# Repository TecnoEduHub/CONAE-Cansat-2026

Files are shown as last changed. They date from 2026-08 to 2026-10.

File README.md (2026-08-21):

# CANSAT 2026 — E.E.S.T. N.º5 "Amancio Williams"

Repositorio destinado a documentar el proceso de participación de la **Escuela de Educación Secundaria Técnica N.º 5 "Amancio Williams" de Mar del Plata** en el **Certamen CANSAT Secundario 2026**, organizado por la **Comisión Nacional de Actividades Espaciales (CONAE)**.

Este repositorio tiene como objetivo conservar el registro del proceso realizado por los estudiantes y docentes de la Técnica N.º 5.

La documentación irá incorporando progresivamente:

- Diseño conceptual.
- Documento Preliminar de Diseño.
- Investigación y antecedentes.
- Diseño electrónico.
- Programación y firmware.
- Diseño mecánico.
- Sistema de descenso.
- Misión primaria.
- Misión secundaria.
- Pruebas y validaciones.
- Fotografías y videos.
- Informes de avance.
- Problemas encontrados y soluciones adoptadas.
- Presentaciones y material de difusión.

La intención es que el repositorio no sea solamente un lugar donde almacenar el resultado final, sino una **bitácora técnica y educativa del proceso de aprendizaje**.

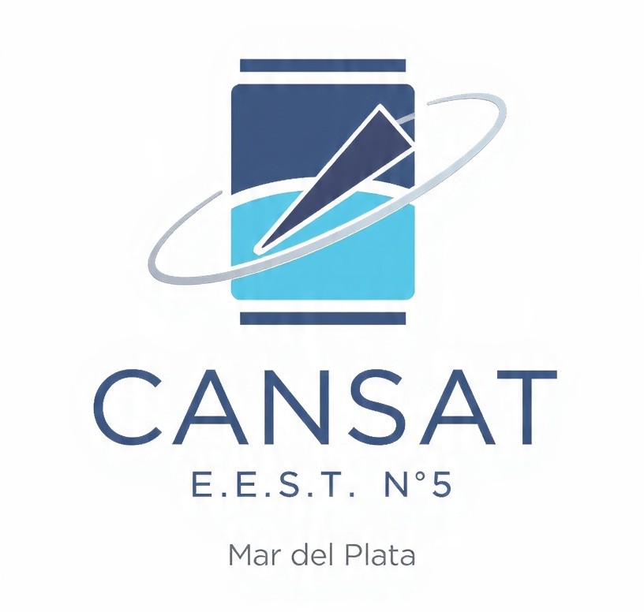
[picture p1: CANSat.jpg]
CANSAT 2026 - Técnica N.º 5


Durante la convocatoria, nuestra institución estuvo representada por dos equipos:

| Equipo | Resultado |
|---|---|
| **A.N.T.I.R.** | Actualmente en la **Etapa 4 — Construcción, seguimiento y validación** |
| **PENTA Space** | Llegó a la **Etapa 3 — Selección de proyectos y recepción del kit** |

Ambos equipos realizaron un excelente trabajo a lo largo de la competencia, atravesando un proceso de aprendizaje que involucró ciencia, electrónica, programación, diseño, experimentación, documentación y trabajo en equipo.

## ¿Qué es CANSAT?

**CANSAT** es una iniciativa educativa vinculada al ámbito espacial que propone a estudiantes de escuela secundaria asumir el desafío de diseñar, construir, probar y operar un **satélite a escala**.

El nombre surge de la combinación de las palabras **CAN** (lata) y **SAT** (satélite), debido a que la carga útil debe estar contenida dentro de un volumen aproximadamente equivalente al de una lata de gaseosa.

En Argentina, la convocatoria es organizada por la **Comisión Nacional de Actividades Espaciales (CONAE)** y busca acercar la ciencia y la tecnología a estudiantes de todo el país. El desafío reproduce, a pequeña escala, distintas etapas de una misión espacial: desde la concepción y el diseño hasta la construcción, validación, lanzamiento y operación del sistema.

Además del desarrollo tecnológico, la propuesta busca fortalecer competencias relacionadas con las disciplinas **STEM —Ciencia, Tecnología, Ingeniería y Matemáticas—**, promover el pensamiento científico y favorecer el trabajo colaborativo.

## El desafío

Cada equipo debe desarrollar una **carga útil** de dimensiones reducidas, contenida dentro de un cilindro de aproximadamente el tamaño de una lata.

El CANSAT es transportado mediante un cohete hasta una determinada altura y posteriormente desciende mediante un sistema de descenso controlado, generalmente un paracaídas. Durante el descenso debe realizar mediciones y transmitir los datos correspondientes a la misión.

La **misión primaria** establecida para CANSAT 2026 consiste en realizar, durante el descenso, un **sondeo atmosférico de presión y temperatura**.

La convocatoria también contempla una **misión secundaria**, mediante la cual cada equipo puede incorporar una actividad adicional. Para esta edición se propuso como objetivo la obtención de una imagen o video durante el lanzamiento, apogeo y/o trayectoria de descenso.

El desafío no consiste únicamente en construir un dispositivo electrónico. Los estudiantes deben trabajar como un verdadero equipo de misión: investigar, diseñar, programar, construir, documentar, realizar pruebas, analizar resultados y comunicar sus decisiones técnicas.

## Etapas de la convocatoria

La competencia se estructura en **cinco etapas eliminatorias**. Cada instancia debe ser aprobada para poder avanzar a la siguiente.

### Etapa 1 — Capacitación

Los estudiantes y docentes participan de una capacitación virtual destinada a incorporar los conocimientos, herramientas y materiales necesarios para desarrollar el proyecto.

La capacitación combina contenidos asincrónicos con instancias sincrónicas y finaliza con una evaluación.

### Etapa 2 — Diseño y presentación del proyecto

Cada equipo debe elaborar y presentar su propuesta.

Entre los principales entregables se encuentran:

- **Documento Preliminar de Diseño (DPD)**.
- **Video de presentación del equipo**.
- Descripción de la misión primaria y secundaria.
- Organización y roles de los integrantes.

La evaluación considera tanto el proyecto técnico como la capacidad del equipo para comunicar sus ideas.

### Etapa 3 — Selección y kit de materiales

Los proyectos son evaluados por un jurado y se seleccionan aquellos que resultan factibles, originales y que evidencian el compromiso y la capacidad de los equipos.

Los proyectos seleccionados reciben un **kit de materiales** para continuar con la construcción del CANSAT.

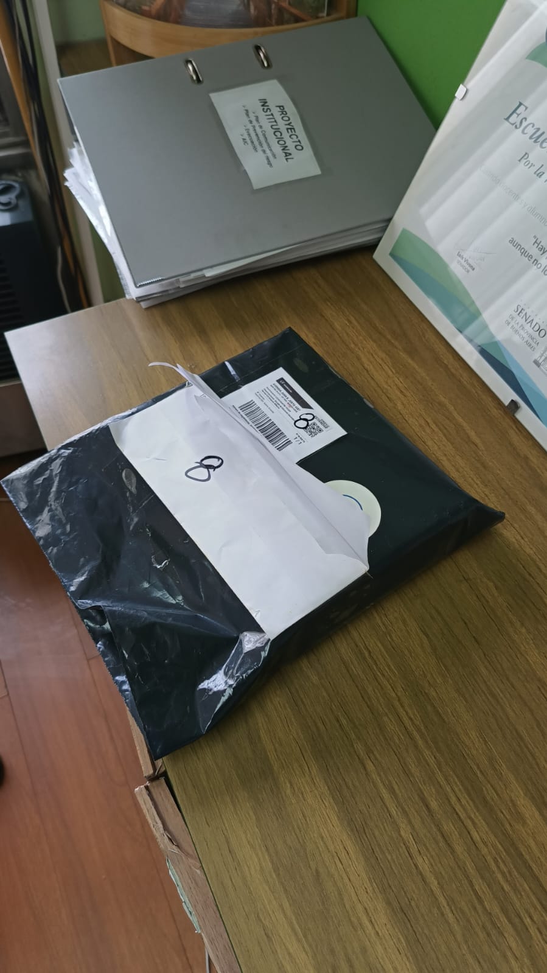
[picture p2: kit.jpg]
Llegada del kit CANSAT a la Técnica N.º 5


**Llegada del kit de materiales de CONAE a nuestra escuela.**

### Etapa 4 — Construcción, seguimiento y validación

Los equipos seleccionados construyen el prototipo diseñado y deben presentar diferentes evidencias de avance, incluyendo documentación, fotografías, videos y otros materiales solicitados.

Al finalizar esta instancia se realiza una validación mediante una videollamada con especialistas, en la que se presenta el prototipo y se revisa su funcionamiento.

De esta instancia se seleccionan los **cinco equipos** que participan de la campaña de lanzamiento, además de las correspondientes menciones especiales.

### Etapa 5 — Campaña de lanzamiento

Los cinco equipos seleccionados participan de la campaña de lanzamiento de sus CANSAT y realizan las mediciones correspondientes.

La convocatoria establece que los equipos seleccionados reciben cobertura de transporte, alojamiento y pensión completa para estudiantes y docentes responsables. 

## Nuestra participación

La Técnica N.º 5 tuvo la posibilidad de presentar **dos equipos** en CANSAT 2026, alcanzando ambos un desempeño destacado.

La convocatoria permite la participación de hasta dos equipos por institución. Cada equipo debe estar integrado por entre tres y cinco estudiantes y contar con el acompañamiento de un docente responsable.

### Equipo A.N.T.I.R.

**A.N.T.I.R.** es uno de los equipos representantes de la Escuela de Educación Secundaria Técnica N.º 5 "Amancio Williams".

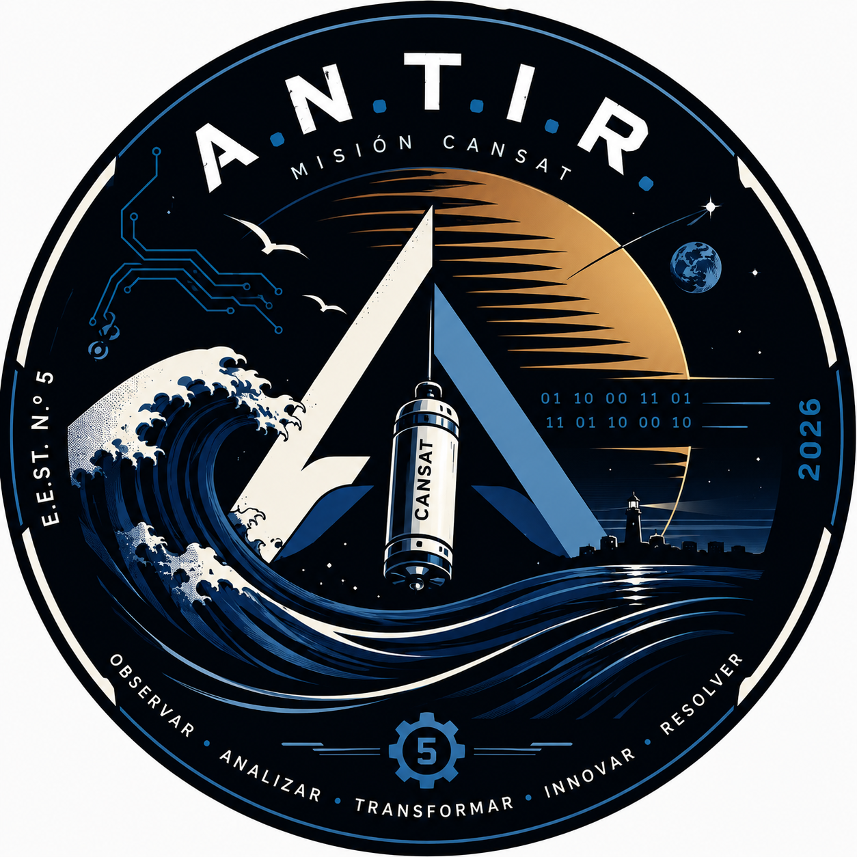
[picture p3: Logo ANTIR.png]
Logo del equipo ANTIR


El equipo actualmente logró avanzar hasta la:

> **Etapa 4 — Construcción, seguimiento y validación de los CANSAT**

Esto implicó superar las etapas iniciales de capacitación, presentación del proyecto y selección de propuestas, para luego recibir el kit de materiales y avanzar en la construcción y validación del prototipo.

En esta etapa el trabajo pasó del diseño conceptual a la implementación concreta: integración de hardware, programación, construcción mecánica, pruebas, documentación y preparación de las evidencias solicitadas por CONAE.

## Equipo PENTA Space

**PENTA Space** fue el segundo equipo que representó a la Técnica N.º 5 "Amancio Williams" en CANSAT 2026.

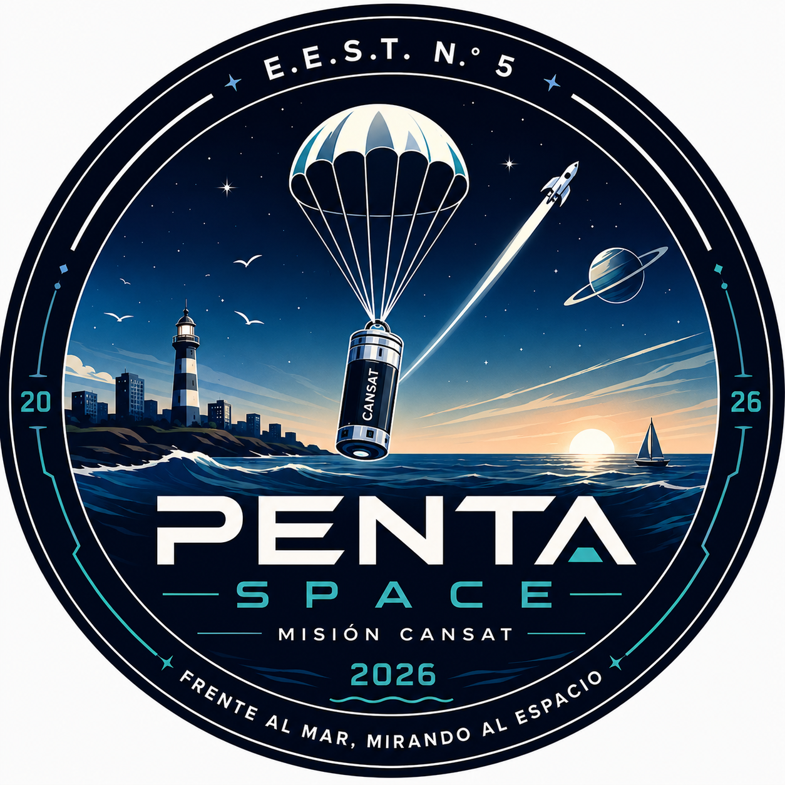
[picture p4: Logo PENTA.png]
Logo del equipo PENTA Space


El equipo logró avanzar hasta la:

> **Etapa 3 — Selección de proyectos y envío del kit de materiales**

Esto significa que su propuesta superó las instancias iniciales de capacitación y evaluación del proyecto, alcanzando la selección que habilitaba a los equipos a continuar con el desarrollo del prototipo.

Aunque el recorrido de PENTA Space finalizó en esta etapa, su participación constituyó un importante proceso de aprendizaje y desarrollo de competencias técnicas y de trabajo en equipo.

## Resultados de la convocatoria

La edición 2026 contó con **257 equipos inscriptos**, de los cuales **120 presentaron su propuesta** mediante el Documento Preliminar de Diseño.

La evaluación estuvo a cargo de un jurado integrado por profesionales de la **Universidad Tecnológica Nacional (UTN)**, la **CONAE** y la **Asociación de Cohetería Experimental y Modelista de Argentina (ACEMA)**.

Los equipos ubicados entre los puestos 1 y 20 fueron invitados a pasar a la siguiente etapa, mientras que los puestos 21 al 40 recibieron una mención de honor por su destacada participación.

La propia organización destacó la elevada calidad de los trabajos presentados y lo ajustado de los puntajes obtenidos. 

## Criterios de evaluación

A lo largo de la convocatoria, los proyectos son evaluados considerando diferentes aspectos:

- **Admisibilidad:** cumplimiento de los requisitos formales.
- **Presentación:** calidad y cumplimiento de las entregas, organización del equipo y comunicación del proyecto.
- **Creatividad:** originalidad del diseño y de la misión secundaria.
- **Viabilidad:** factibilidad de realización y planificación de las pruebas.
- **Relevancia:** claridad, pertinencia, grado de avance y complejidad de la propuesta.

Estos criterios hacen que CANSAT sea mucho más que una competencia de construcción de un dispositivo: el proceso completo de planificación, documentación, validación y comunicación forma parte del desafío. 

## Recursos

- [Capacitación y videos del proyecto](https://drive.google.com/drive/folders/1EPjXjjoXwsOttx_nsDYTwsNPLpWK6ylc?usp=sharing)

- [Comisión Nacional de Actividades Espaciales](https://www.argentina.gob.ar/ciencia/conae)

- [Asociación de Cohetería Experimental y Modelista Argentina](https://www.acema.com.ar/)

## Agradecimientos

A la **Comisión Nacional de Actividades Espaciales (CONAE)** por impulsar esta propuesta educativa y brindar a estudiantes de escuelas secundarias de todo el país la posibilidad de acercarse al desarrollo de tecnología espacial.

A **ACEMA** y a todos los profesionales que participaron de la capacitación, evaluación y acompañamiento de los equipos.

Y, especialmente, a los estudiantes de **A.N.T.I.R.** y **PENTA Space**, por el compromiso, la creatividad, el trabajo técnico y la dedicación demostrados durante todo el proceso.

Independientemente de la etapa alcanzada por cada equipo, ambos representaron a la **Escuela de Educación Secundaria Técnica N.º 5** y dejaron un valioso registro de aprendizaje, experimentación y trabajo colaborativo.

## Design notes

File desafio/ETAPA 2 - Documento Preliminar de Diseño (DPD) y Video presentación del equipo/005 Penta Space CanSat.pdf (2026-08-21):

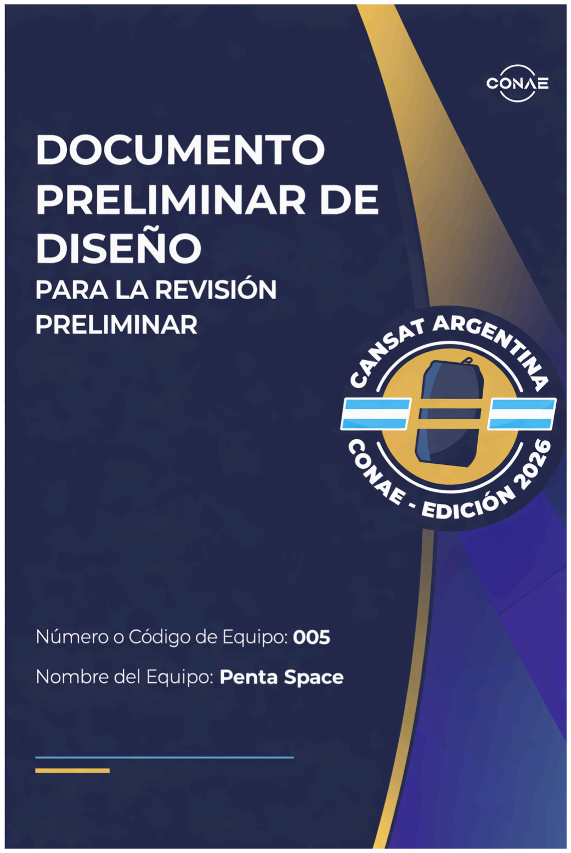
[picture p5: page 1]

# DATOS

CÓDIGO CONAE (NRO):
005

NOMBRE DEL EQUIPO:
Penta Space

Colegio/Institución:
E.E.S.T. N.°5 Amancio Williams (Mar Del Plata)

Miembros del equipo:
-Geronimo Octavio Luciano Villagran -Acosta Pedro
-Petagna Ordoñez Bautista Jeremias -Tiago Lionel Ramirez
-Mauro Nehemias Castro

Tutor responsable:
- Lucas Martin Treser

# NOMBRE DE LA MISIÓN

Parche:

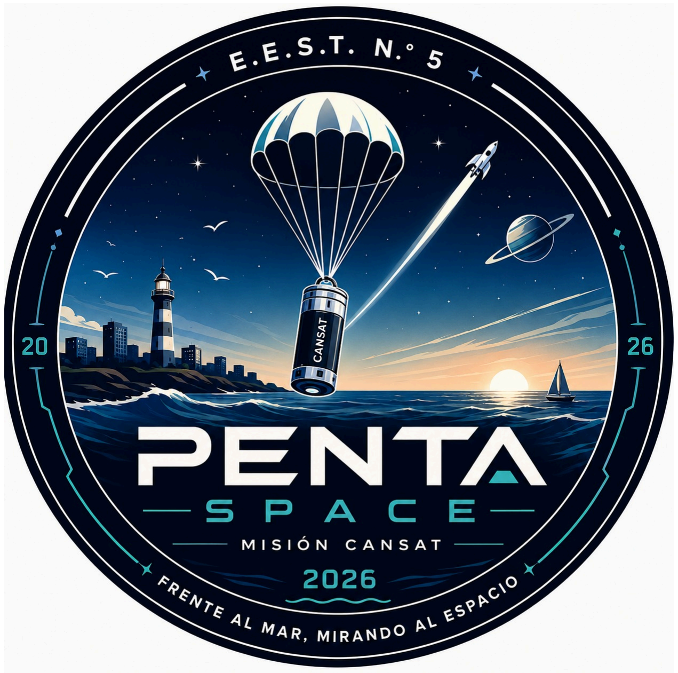
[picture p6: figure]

Organización del equipo: Roles
Geronimo Octavio Luciano Villagran: Desarrollo de Hardware Acosta Pedro: Estructura y Diseño
Petagna Bautista: Programación y comunicación
Tiago Lionel Ramirez: Montaje y Soldadura
Mauro Nehemias Castro: Organización y telecomunicación

# Objetivos de la misión

La misión primaria es:
Realizar un sondeo durante el descenso del CanSat y nos piden medir únicamente presión y temperatura, a su vez resistir el lanzamiento, la caída y el impacto.
Debemos de diseñar una carcasa capaz de soportar los componentes que tenga dentro de ella (microcontroladores, carga útil, etc)
Queda totalmente prohibido que la carcasa sea de materiales tóxicos al ser humano o que contaminen el medio ambiente o tener material peligroso en el CanSat (por ejemplo químicos o explosivos)

La misión secundaria que proponemos es:
-Grabar video/ sacar fotos
-Medir la radiación uv
-Medición de la humedad
-Altura
-Ubicación geográfica

Todas estas mediciones se registrarán en base a la altura para tener un criterio al cual tener una referencia de registro para calcular a qué altura aumentan o disminuyen estas mediciones.

Justificación: La misión secundaria del CanSat busca ayudarnos a entender mejor cómo se comportan los fenómenos atmosféricos y a poner en práctica la integración de distintos sistemas en una plataforma muy pequeña. Vamos a medir humedad, radiación UV, temperatura y altura para analizar cómo cambian las condiciones de la atmósfera a medida que el satélite desciende. Estos datos pueden servir para estudios meteorológicos, ambientales y también para aprender más en el ámbito educativo. Además, el uso de una cámara y la transmisión de imágenes por el enlace NRF nos permitirá relacionar las observaciones visuales con los datos físicos obtenidos.

# DISEÑO PRELIMINAR

LAYOUT FÍSICO: Esta es la base del diseño exterior del CanSat. La estructura podrá estar sujeta a modificaciones y mejoras durante el desarrollo del proyecto, pero se mantendrá el orden general de los módulos y componentes dispuesto en la imagen.

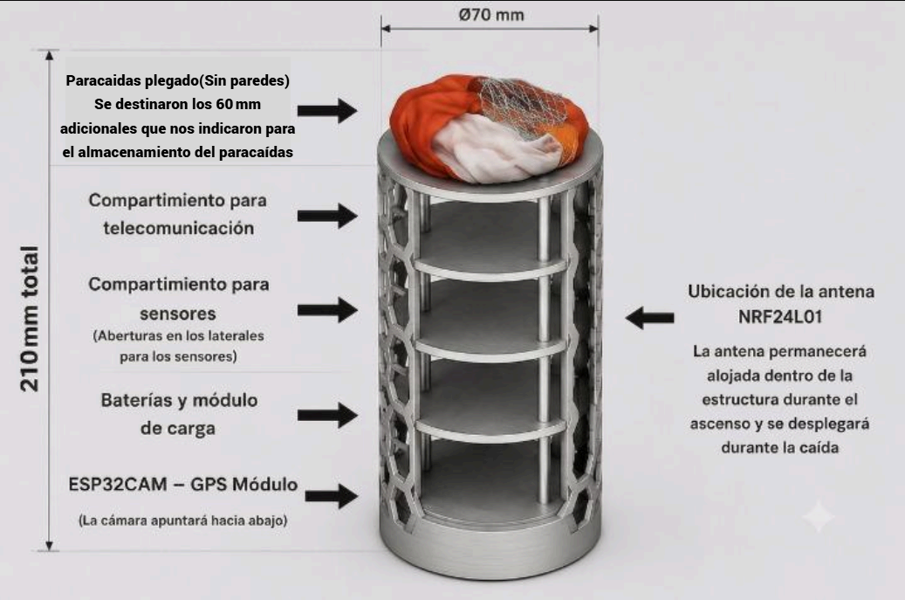
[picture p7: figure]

OPERACIONES:
Comportamiento de carga útil:
La carga útil deberá mantener un funcionamiento estable y confiable durante las fases del vuelo. Se espera que los sensores y sistemas electrónicos operen correctamente desde el lanzamiento hasta el aterrizaje y recuperación, garantizando la adquisición y transmisión de datos. Durante el descenso del CanSat, los sensores iniciarán las mediciones y recopilarán los datos atmosféricos y de movimiento, mientras el sistema de telecomunicaciones enviará la información hacia la estación terrena. Se espera detectar y registrar las variaciones de temperatura, presión atmosférica y altitud, junto con otros parámetros relevantes, reflejando los cambios que ocurren conforme el satélite desciende.

# SUBSISTEMAS

Un subsistema es un conjunto de componentes que forma parte de un sistema mayor y cumple una función específica dentro de él. Aunque cada subsistema puede realizar tareas particulares, todos trabajan de manera coordinada e interconectada para que el sistema completo cumpla su misión.

Electrónica: Es el subsistema encargado de adquirir, procesar y gestionar la información proveniente de los distintos sensores y dispositivos del CanSat.

Los componentes que se utilizarán son:

-ESP32-CAM S3: Microcontrolador principal con cámara integrada. Se encarga de capturar imágenes, procesar los datos de los sensores y controlar el funcionamiento general del sistema.
-Módulo + PA/LNA: Módulo de comunicación por radiofrecuencia de corto y medio alcance (2,4 GHz).
-Módulo LoRa: Módulo de comunicación por radiofrecuencia de largo alcance.
-Sensor BME280: Mide presión atmosférica, temperatura y humedad. -Sensor UV ML8511: Mide el nivel de radiación ultravioleta.
-GPS NEO-7M: Proporciona la posición geográfica (latitud y longitud) y la altitud del CanSat.
Electrónica de potencia: Es el subsistema encargado de suministrar, distribuir y regular la energía eléctrica necesaria para el funcionamiento de todos los componentes. Se utilizarán baterías 18350, elegidas por su tamaño compacto y su capacidad energética.
Telemetría: Es el subsistema encargado de transmitir la información obtenida por los sensores hacia la estación terrenal.
Para ello se utilizará un módulo de radiofrecuencia NRF24L01 + PA/LNA, que enviará los datos capturados por los sensores y las imágenes obtenidas por la cámara(Además de guardarlas en la tarjeta SD del módulo), permitiendo el monitoreo del CanSat en tiempo real.
Cámara: Es el subsistema encargado de capturar imágenes durante toda la misión. La cámara estará integrada en la ESP32-CAM, recibirá alimentación del subsistema de potencia y las imágenes podrán ser transmitidas mediante el sistema de telemetría o a través de la tarjeta sd del módulo.
Sistema de descenso: Es el subsistema responsable de garantizar un descenso seguro y controlar la velocidad de caída del CanSat.
Se utilizará un paracaídas, cuya función será reducir la velocidad de descenso para proteger la electrónica, la estructura y la carga útil durante el aterrizaje, además de asegurar una velocidad adecuada para realizar mediciones precisas durante la fase de descenso.

# PRESUPUESTO DE MASA

Componente | Cantidad | Masa Unitaria (g) | Masa Total (g)
ESP32-CAM | 1 | 18 | 18
Módulo NRF24L01+ PA/LNA (a bordo) | 1 | 24 | 24
Módulo LoRa (a bordo) | 1 | 8 | 8
Sensor BME280 | 1 | 3 | 3
Sensor UV ML8511 | 1 | 2 | 2
GPS NEO-7M | 1 | 18 | 18
Batería Li-ion 18350 | 2 | 23 | 46
Módulo de carga TP4056 | 1 | 3 | 3
PCB personalizada FR4 optimizada | _ | 18 | 18
Carcasa impresa en PLA optimizada | 1 | 50 | 50
Paracaídas Ripstop Ø50 cm + 8 cuerdas | 1 | 22 | 22
Cableado y conectores | _ | _ | 10
Tornillería y separadores optimizados | _ | _ | 10
Masa total estimada | _ | _ | 232g

El presupuesto de masas se realizó considerando únicamente los componentes de la carga útil del CANSAT. Las masas se obtuvieron a partir de las especificaciones técnicas de los fabricantes y de estimaciones para los elementos de fabricación propia, como la PCB y la carcasa impresa en PLA. La masa total estimada es de 232g, cumpliendo con las restricciones del proyecto y dejando un margen para posibles ajustes durante la integración. Antes del lanzamiento, se verificará la masa total del sistema mediante una balanza digital de precisión.

# INTEGRACIÓN Y PRUEBAS

### Pruebas preliminares de los componentes:

Antes de realizar el ensamblaje definitivo del CanSat, se verificará de manera individual el correcto funcionamiento y calibración de cada periférico aprovechando las instalaciones escolares y entornos públicos cercanos:

Sensor BME280 (Presión, Temperatura y Humedad): Se realizarán mediciones iniciales en ambientes controlados dentro de las aulas y talleres del colegio para registrar la estabilidad térmica y de humedad. Para comprobar el correcto funcionamiento del barómetro respecto a las variaciones de altitud, se utilizarán las escaleras de la institución y el puente de la escuela (de interconexión de las aulas), contrastando los cambios de presión relativa con la altura geométrica real de los pisos.

Sensor UV ML8511 (Radiación Ultravioleta): Se medirá su respuesta en zonas interiores bajo luz artificial (donde el nivel de radiación UV debe aproximarse a cero). Posteriormente, el equipo se trasladará a espacios abiertos (como el patio del colegio o la plaza pública cercana) expuesto directamente a la radiación solar para validar el incremento en el voltaje de salida y su correcta fluctuación de acuerdo con la intensidad del sol.

GPS NEO-7M (Posición y Altitud): Las pruebas se llevarán a cabo al aire libre en la plaza o patio del colegio para asegurar una línea de visión directa y despejada con las constelaciones satelitales. Se registrará el tiempo de adquisición de señal (Time-To-First-Fix) y se validará que las coordenadas obtenidas correspondan con precisión a la localización geográfica en Mar del Plata.

ESP32-CAM S3 y Módulos de Comunicación (NRF24L01+ / LoRa): Se realizarán pruebas de transmisión de datos en tiempo real y captura de imágenes desde dependencias internas críticas como el Zoom y los talleres. Esto permitirá evaluar el alcance de los módulos de radiofrecuencia a través de obstáculos y muros, garantizando la estabilidad del enlace de telemetría.

### Secuencia de integración:

El proceso de ensamblaje físico y eléctrico del satélite se llevará a cabo de manera estructurada siguiendo los siguientes pasos consecutivos:

Inspección de la PCB: Revisión visual de la placa personalizada FR4 para comprobar la ausencia de cortocircuitos o fallas de continuidad en las pistas.

Montaje del Subsistema de Potencia: Soldadura del módulo de carga TP4056 y los portabaterías para las celdas Li-ion 18350. Se medirá con un multímetro digital que los voltajes de alimentación regulados (3.3V y 5V) sean estables.

Fijación del Microcontrolador y Módulos RF: Soldadura o inserción de la ESP32-CAM S3 y de las placas de comunicación NRF24L01+ y LoRa sobre la PCB.

Integración de Sensores Periféricos: Conexión de los sensores previamente validados (BME280, ML8511 y GPS) a los pines correspondientes de la placa madre.

Carga y Testeo del Firmware Base: Programación del firmware para verificar que la ESP32-CAM logre inicializar y leer todos los sensores simultáneamente sin congelamientos.

Encapsulado Mecánico: Introducción y fijación de la electrónica armada dentro de la carcasa impresa en PLA optimizada utilizando la tornillería y separadores correspondientes.

Anclaje del Sistema de Descenso: Sujeción de las líneas de cuerda del paracaídas Ripstop de a los puntos de sujeción de la estructura exterior. Pruebas de integridad:
Una vez integrado por completo el CanSat dentro de su contenedor, se someterá al conjunto a ensayos mecánicos y funcionales globales:

Prueba de Continuidad Operativa: Con el CanSat totalmente sellado, se encenderá mediante sus baterías y se dejará transmitiendo telemetría continua hacia la estación terrena por un lapso mínimo de 30 minutos. Se evaluará que no existan pérdidas de paquetes ni caídas de tensión eléctrica.

Prueba de Resistencia Mecánica y Vibración: Se realizarán pruebas manuales de agitación rigurosa en el taller para asegurar que el hardware interno permanezca firme y que ningún cable, conector o batería se desconecte ante las aceleraciones bruscas del lanzamiento.

Prueba de Despliegue del Paracaídas: Se simularán lanzamientos de caída libre controlada arrojando el CanSat de forma segura desde el puente de la institución o ventanas elevadas hacia una zona acolchada, verificando la apertura inmediata y correcta del paracaídas Ripstop, asegurando una velocidad de descenso controlada.

Plan de validación (medidas, peso, integridad, tests ambientales): Para garantizar que el prototipo cumple estrictamente con el reglamento de CONAE y que sus mediciones son fiables, se ejecutará el siguiente plan métrico:

Validación de Mediciones (Consistencia de Datos): Para certificar que lo que medimos está bien, las lecturas en tiempo real de telemetría ambiental se compararán lado a lado con instrumental de referencia comercial de taller (como un termómetro/higrómetro digital externo para contrastar el BME280) y dispositivos GPS móviles redundantes para comprobar la consistencia de coordenadas y altitudes del NEO-7M.

Validación de Peso (Presupuesto de Masa): El CanSat finalizado se colocará sobre una balanza digital de precisión del colegio para certificar que el peso total se ajusta a la masa estimada de 232 g, garantizando que permanezca holgadamente dentro de las restricciones reglamentarias de la misión.

Validación Dimensional (Medidas): Se utilizará un calibre métrico industrial para registrar el diámetro y altura final de la carcasa de PLA, verificando que respete el factor de forma cilíndrico estándar exigido (símil lata de bebida).

Tests Ambientales Térmicos: Para asegurar el comportamiento frente a bajas temperaturas en la atmósfera alta, se introducirá el sistema encendido dentro de una caja térmica refrigerada con hielo, supervisando que ni las baterías ni el procesamiento de la ESP32-CAM sufran degradación bajo condiciones climáticas frías.

# OPERACIÓN DE LA MISIÓN

Secuencia de eventos prevista:

Preparación: verificación del funcionamiento de los sensores, cámara, batería, sistema de almacenamiento y comunicaciones.
Integración: instalación del CanSat en el vehículo lanzador de acuerdo con los procedimientos establecidos por CONAE.
Lanzamiento: el CanSat es elevado hasta una altura aproximada de 200 a 400 metros.
Separación: el CanSat es liberado e inicia el descenso mediante un paracaídas. Desarrollo de la misión: durante el descenso se registran mediciones de temperatura, humedad, presión atmosférica, altitud, radiación UV y calidad del aire, mientras la cámara captura imágenes y/o video. Los datos se almacenan y, cuando es posible, se transmiten a la estación terrena.
Aterrizaje: el CanSat desciende de forma controlada y es recuperado por el equipo.
Recepción y análisis de datos: se descargan y procesan las mediciones e imágenes obtenidas para evaluar el desempeño del sistema y analizar las condiciones ambientales registradas durante la misión.
Roles y responsabilidades en la operación de la misión:

Director de misión: Coordina las actividades durante la campaña, supervisa la operación del CanSat y mantiene la comunicación con la organización.

Responsable de hardware: Verifica el estado de la electrónica, sensores, batería y conexiones antes de la integración y el lanzamiento.

Responsable de software y telemetría: Supervisa el funcionamiento del programa, la adquisición de datos y la recepción de la telemetría durante la misión.

Responsable de estación terrena: Monitorea la información recibida en tiempo real, registra los datos y verifica el estado del CanSat durante el descenso.

Responsable de recuperación y análisis: Coordina la recuperación del CanSat tras el aterrizaje y realiza la descarga, procesamiento y análisis de los datos obtenidos.

# PRESUPUESTO Y CAPACIDADES

Presupuesto de Componentes
El siguiente cuadro detalla el presupuesto estimado de los componentes utilizados para el desarrollo de la carga útil del CanSat.
Nota: Los valores expresados son estimaciones de mercado y deben ser verificados con los costos reales de adquisición del equipo.
Componente | Cantidad | Costo Unitario Est. (ARS) | Costo Total Est. (ARS)
ESP32-CAM S3 | 1 | ≈$25.000
Módulo NRF24L01+ PA/LNA | 1 ≈ $9.000
Módulo LoRa | 1 | ≈ $ 15.000
Sensor BME280 | 1 | ≈ $ 10.000
Sensor UV ML8511 | 1 | ≈ $ 8.000
GPS NEO-7M | 1 | ≈ $ 22.000
Batería Li-ion 18350 | 2 | $8.000 \$ 16.000
Módulo de carga TP4056 | 1 | ≈ $ 2.500

PCB, Carcasa (PLA) y Paracaídas | 1 ≈ $ 15.000
Varios (Cables, conectores, tornillos) | - ≈ $ 5.000
Costo Total Estimado | | $ 127.500

Capacidades del Equipo e Institución

Para garantizar el desarrollo, construcción y puesta en marcha exitosa del CanSat "Penta Space", el equipo cuenta con una sólida base de capacidades técnicas, asesoramiento profesional e infraestructura tecnológica aportada por la
E.E.S.T. N.°5:

Conocimientos y Habilidades del Equipo: El grupo se encuentra organizado de forma estratégica dividiendo las tareas según las especialidades y competencias individuales adquiridas a lo largo de la formación técnica:

Desarrollo de Hardware y Soldadura: Contamos con capacidades para el diseño de circuitos electrónicos, diseño de placas de circuito impreso (PCB) en software EDA y técnicas de soldadura blanda de precisión para componentes electrónicos y de montaje superficial (SMD).

Programación y Telecomunicaciones: Dominio en entornos de desarrollo (como Arduino IDE / VS Code) y lenguaje C/C++ enfocado a sistemas embebidos, algoritmos de lectura de sensores, gestión de memoria en la ESP32-CAM y configuración de protocolos de comunicación por radiofrecuencia (SPI, I2C, UART) para la telemetría.

Diseño Mecánico y Estructura: Experiencia en modelado 3D mediante software CAD (como SolidWorks o Fusion 360), lo que nos permite calcular tolerancias mecánicas, optimizar el peso de la carcasa de PLA y diseñar un sistema aerodinámico y resistente a impactos.

Organización y Logística: Capacidad para la gestión de tareas, documentación del proyecto, cronogramas de trabajo y control del presupuesto.

Infraestructura y Herramientas del Colegio: La institución educativa nos provee de un entorno de taller y laboratorios completamente equipados, lo que reduce a cero la necesidad de tercerizar la fabricación:

Laboratorio de Electrónica: Acceso a instrumental de medición y diagnóstico como multímetros digitales, osciloscopios (para verificar las señales de los módulos RF) y fuentes de alimentación reguladas para las pruebas de banco.

Estaciones de Soldadura: Disponibilidad de soldadores tipo lápiz, estaciones de aire caliente, flux y herramientas de corte/sujeción necesarias para el ensamblaje seguro de la PCB.

Entorno de Fabricación Digital (Impresión 3D): Uso de las impresoras 3D del colegio para la materialización física de la carcasa en plástico PLA, permitiéndonos hacer prototipos rápidos y corregir errores de diseño sobre la marcha.

Aulas de Informática: Computadoras con el software necesario para la programación del microcontrolador y la configuración de la interfaz de la estación terrena.

Asesoramiento y Acompañamiento Docente: Contamos con la guía constante de nuestro tutor responsable, el profesor Lucas Martin Treser, quien aporta su experiencia técnica y pedagógica para supervisar el avance del proyecto, validar los diagramas eléctricos y coordinar el uso seguro de los talleres. Asimismo, el equipo tiene la posibilidad de consultar a otros profesores especializados de las áreas de electrónica e informática de la institución ante desafíos puntuales en la integración de sistemas o la calibración de sensores.

# AGENDA

CRONOGRAMA:

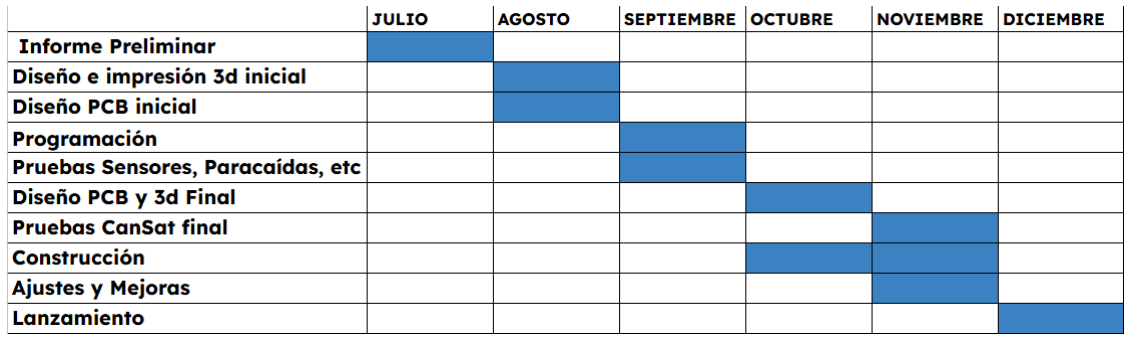
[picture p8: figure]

PLAN DE DOCUMENTACIÓN:
El proceso será documentado a través de fotografías y videos de las distintas etapas del proyecto, incluyendo el diseño, la construcción, las pruebas y la investigación, así como los resultados obtenidos, con el fin de mantener un seguimiento del desarrollo del proyecto que respalde la elaboración del informe técnico.

PLAN DE PUBLICACIÓN Y DIFUSIÓN DE RESULTADOS:
Para difundir los avances y resultados del proyecto se utilizarán las redes sociales, como Instagram y YouTube. En caso de avanzar a la siguiente etapa, se crearán las cuentas oficiales del equipo para la difusión. Donde se publicarán fotografías, videos e información sobre las actividades realizadas. Así, se compartirá la experiencia del equipo, se dará a conocer el proyecto y se acercará la iniciativa a la comunidad educativa y al público interesado.

# VIDEO

LINK A VÍDEO:
https://youtube.com/shorts/Je65-AJ7Xck?feature=share

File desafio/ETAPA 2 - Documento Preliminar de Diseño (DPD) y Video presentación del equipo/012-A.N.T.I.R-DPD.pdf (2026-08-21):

# DOCUMENTO PRELIMINAR DE DISEÑO

# PARA LA REVISIÓN PRELIMINAR

Número o Código de Equipo: 012

Nombre del Equipo: A.N.T.I.R

## DATOS (2) (OBLIGATORIO)

CODIGO CONAE (NRO): 012

NOMBRE DEL EQUIPO: A.N.T.I.R

Colegio / Institución: EEST 5 "Amancio Williams" (MDQ)

Miembros del equipo:
- Hernández, Azul.
- Agostinelli, Nefíah.
- Iacono, Tiziano.
- García, Ian.
- Zamudio, Román.
Tutor responsable: Treser, Lucas

## NOMBRE DE LA MISIÓN (6)

Parche

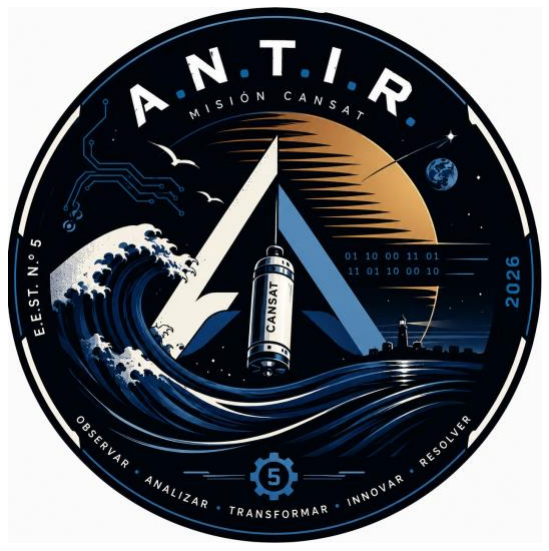
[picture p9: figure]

Organización del equipo: roles Líder de Grupo: Agostinelli, Nefíah. Diseño: García, Ian.
Electrónica: Iacono, Tiziano. Programación: Zamudio, Román. Investigación: Hernández, Azul.

## OBJETIVOS (6)

Misión primaria
La misión primaria consiste en realizar un sondeo atmosférico durante el vuelo del CanSat. Se medirán de forma continua los siguientes parámetros:
- Presión atmosférica y temperatura (sensor BMP280)
- Aceleración y velocidad angular (sensor MPU6050)
- Posición geográfica: latitud, longitud y altitud (módulo GPS NEO-8M)
Los datos serán almacenados localmente en una tarjeta MicroSD y transmitidos en tiempo real a la estación terrena mediante el módulo LoRa SX1278. El objetivo es obtener un perfil atmosférico del ascenso y descenso, junto con la trayectoria del CanSat. .Lo más relevante según las bases y condiciones de la instancia es la Presión atmosférica y temperatura.
Misión secundaria
La misión secundaria consiste en la captura de imágenes de la zona costera durante el descenso del CanSat, utilizando una ESP32-CAM orientada hacia el suelo.
El objetivo es realizar un análisis visual preliminar del estado de la costa de Mar del Plata, prestando especial atención a la posible presencia de acumulaciones de residuos en la línea de playa. Las imágenes obtenidas se almacenarán en una tarjeta MicroSD para su posterior procesamiento y evaluación en tierra.
Si bien las condiciones de vuelo (altura, resolución de la cámara y tiempo de descenso) no permiten realizar un mapeo de alta precisión, esta observación exploratoria busca identificar zonas de interés y evaluar el potencial de este tipo de plataformas de bajo costo para el monitoreo costero.
La idea es tener un seguimiento sistemático de la contaminación en las playas para conocer su evolución a lo largo del tiempo. La información recopilada permitirá documentar el estado ambiental, trabajar en conjunto con organizaciones locales y visibilizar los avances alcanzados en la reducción de esta problemática.
Asimismo, se busca generar un registro que permita identificar la trazabilidad de la contaminación, aportando evidencia útil para la planificación, el diseño y la evaluación de futuras políticas públicas orientadas a la protección y conservación del ambiente costera

## DISEÑO PRELIMINAR (25) H2

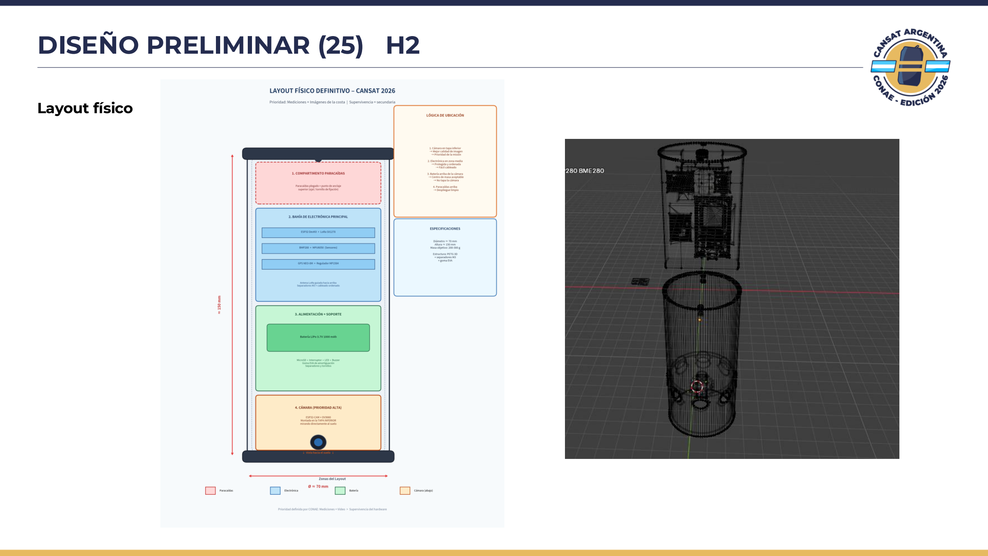
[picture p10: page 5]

Layout físico

## DISEÑO PRELIMINAR (25) H2

Como funciona: Operaciones
Misión primaria (sondeo atmosférico): Durante el ascenso y el descenso, el ESP32 DevKit adquiere periódicamente datos de presión, temperatura (BMP280), aceleración y orientación (MPU6050) y posición (GPS NEO-8M). Estos datos se almacenan en la MicroSD y se transmiten en tiempo real a la estación terrena mediante el módulo LoRa SX1278.
Misión secundaria (filmación): La ESP32-CAM, montada en la tapa inferior y orientada hacia el suelo, captura imágenes durante el descenso. Las fotografías se guardan en la MicroSD para su posterior análisis visual orientado al estado de la costa y posibles acumulaciones de residuos.

Una vez encendido el sistema, el ESP32 DevKit comienza a ejecutar el programa principal de forma cíclica. En cada ciclo realiza las siguientes operaciones:
- Lectura de sensores Adquiere datos del BMP280 (presión, temperatura) y del MPU6050 (aceleración y velocidad angular) a través del bus I2C.
- Lectura de posición Obtiene las coordenadas de latitud, longitud y altitud del módulo GPS NEO-8M mediante UART.
- Captura de imagen (misión secundaria) Envía la orden a la ESP32-CAM para tomar una fotografía. La imagen se almacena en la MicroSD.
- Almacenamiento local Todos los datos de sensores, GPS y el registro de las fotos tomadas se guardan en la MicroSD como respaldo.
- Transmisión de telemetría Los datos más relevantes se envían en tiempo real a la estación terrena a través del módulo LoRa SX1278 (SPI).

## SUBSISTEMAS (12)

Subsistema | Descripción | Componentes principales
Estructura | Carcasa protectora impresa en 3D que sostiene y protege todos los componentes internos. | Chasis PETG, tornillos, separadores, goma EVA
Electrónica: Sensores | Mide los parámetros ambientales y de movimiento durante el vuelo. | BMP280 (temperatura, presión) + MPU6050 (aceleración)+ GPS NEO-8M (posicionamiento)
Electrónica: Potencia | Alimenta todos los sistemas del CanSat de forma estable. | Batería LiPo 3,7 V 1000 mAh + regulador MP1584
Electrónica: Telemetría | Transmite los datos en tiempo real a la estación terrena y guarda respaldo. | Módulo LoRa SX1278
Electrónica: Cámara | Captura las imágenes para la misión secundaria (análisis de la costa). | ESP32-CAM + sensor OV3660 + lente
Electrónica: Procesamiento | Microcontrolador principal. | ESP32 DevKit
Electrónica: Almacenamiento | Guarda todos los datos adquiridos en el trayecto | MicroSD
Sistema de descenso | Reduce la velocidad de caída para un aterrizaje seguro. | Paracaídas + cuerdas

## SUBSISTEMAS (12)

El sistema de Potencia (batería + regulador) alimenta a 3.3 V a todos los módulos electrónicos del CanSat.
El ESP32 DevKit funciona como cerebro central: recibe los datos de los sensores y del GPS, controla la cámara y envía la información a través de la telemetría.
Los Sensores (BMP280 y MPU6050) miden presión, temperatura, y movimiento, y envían esa información al ESP32 por I2C.
El GPS NEO-8M entrega la posición (latitud, longitud y altitud) al ESP32 por UART.
La Cámara (ESP32-CAM) captura las imágenes de la misión secundaria, las guarda en la MicroSD y se comunica con el microcontrolador principal.
La Telemetría (LoRa SX1278) transmite en tiempo real los datos procesados hacia la estación terrena.
La Estructura protege físicamente a todos los componentes durante el vuelo y el aterrizaje. El Sistema de descenso (paracaídas) reduce la velocidad de caída para que el CanSat llegue intacto al suelo.

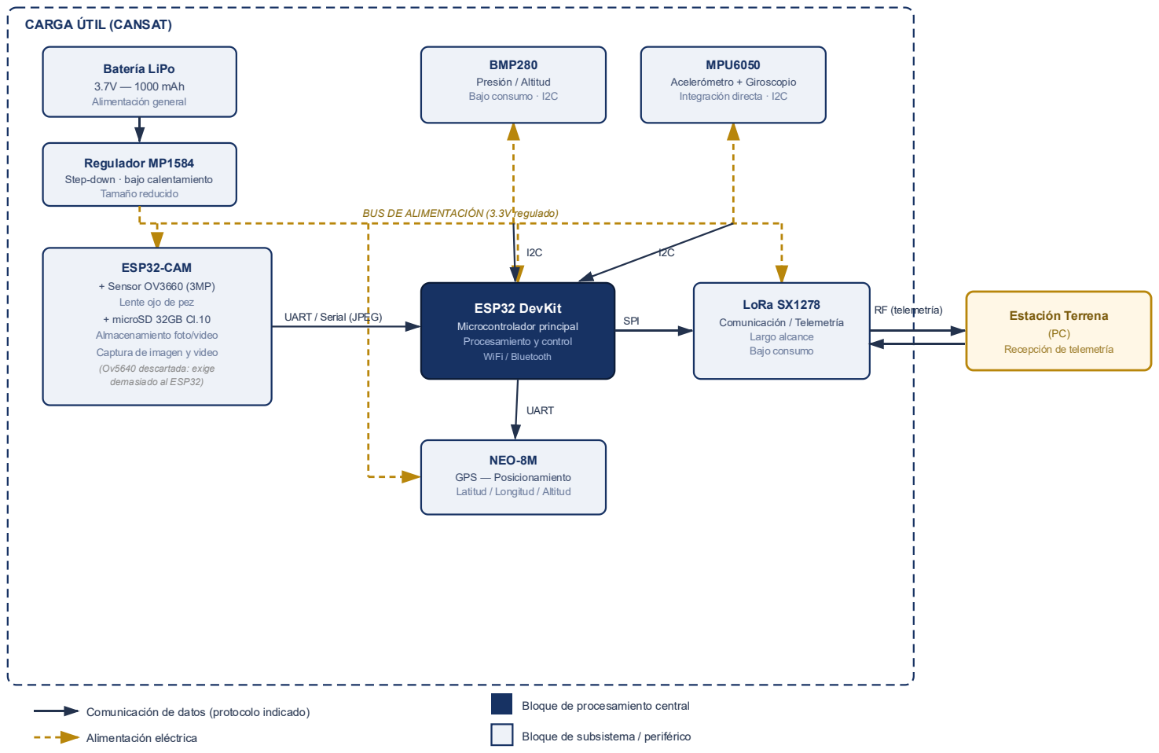
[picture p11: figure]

## PRESUPUESTO DE MASAS (4)

Componente | Peso (g)
ESP32 DevKit (micro principal) | 12
ESP32-CAM + OV3660 + lente | 10
MicroSD 32 GB | 1
Módulo GPS NEO-8M (con antena) | 18
Sensor BMP280 | 2
Sensor MPU6050 | 3
Módulo LoRa SX1278 (con antena) | 15
Batería LiPo 3,7 V 1000 mAh | 22
Regulador MP1584 | 3
Cables, conectores y plaqueta | 20
Estructura (chasis 3D + tornillos, etc.) | 80
Paracaídas y cuerdas | 25
Peso total aproximado: | 211

## INTEGRACIÓN Y PRUEBAS (12) H1

Pruebas preliminares de los componentes
Antes de armar el CanSat completo se probará cada parte por separado:
- BMP280: verificar que entregue valores correctos de temperatura, presión .
- Cámara OV3660: comprobar que tome fotos y las guarde correctamente en la MicroSD.
- LoRa SX1278: probar el alcance y la recepción de datos en la estación terrena.
- GPS NEO-8M: verificar que fije posición.
- MPU6050: comprobar lectura de aceleración.
- Batería + regulador: medir voltaje de salida y autonomía aproximada.
- Paracaídas: prueba de apertura manual.
Pesaje de cada componente: Para calcular y asegurar que no nos vamos a exceder del presupuesto de Masas.

Secuencia de integración
- 1) Soldar y montar los componentes electrónicos en el PCB.
- 2) Conectar sensores, cámara, LoRa, GPS y MPU6050 al ESP32.
- 3) Instalar la batería y el regulador de voltaje.
- 4) Colocar todo el conjunto electrónico dentro de la estructura impresa en 3D, usando separadores y goma EVA para protegerlo.
- 5) Fijar la cámara apuntando hacia abajo.
- 6) Colocar el paracaídas en su compartimento superior y asegurar las líneas.
- 7) Cerrar la estructura y verificar que no haya piezas sueltas.
- 8) Realizar un encendido completo para comprobar que todo funciona junto.

## INTEGRACIÓN Y PRUEBAS (12) H2

Pruebas de integridad
Después de armar el CanSat se realizarán las siguientes verificaciones:
- Encendido completo y comprobación de que todos los sensores envían datos.
- Verificación de que la cámara guarda fotos en la MicroSD.
- Comprobación de la transmisión LoRa hacia la estación terrena.
- Medición del peso total y de las dimensiones finales.
- Revisión visual de que no haya cables sueltos ni interferencias mecánicas.

Plan de validación (medidas, peso, integridad, tests ambientales)
- Test de caída: Se lanzará el CanSat desde 3–5 metros de altura con el paracaídas desplegado.
El objetivo será Verificar que el paracaídas abra bien y que la estructura resista el impacto. (meteremos un payload falso, para no arriesgar la integridad del payload final).
- Test de vibraciones: Se someterá el CanSat a vibraciones (usando un parlante o vehículo)
El objetivo será Comprobar que no se desconecte nada ni se rompan componentes.
- Verificación de Medidas: Mediremos la altura y diámetro final para asegurar que el CanSat cumpla con las normativas.
- Simulación de vuelo completo en tierra: Básicamente iniciaremos el CanSat y pasearemos con él, moviéndolo con la intención de que nos arroje medidas y asegurarnos de que las transmita correctamente. (La intención es alejarlo del receptor hasta la mayor distancia posible).

## OPERACIÓN DE LA MISIÓN (6)

Secuencia de eventos prevista
- Verificación previa: Se revisa la batería, todos los subsistemas y se comprueba la correcta comunicación de la telemetría con la estación terrena.
- Integración al cohete: Se coloca el CanSat en el compartimento de carga útil y se verifica el sistema de descenso.
- Lanzamiento y ascenso: El cohete despega. Durante el ascenso se registran datos de sensores, GPS y se capturan imágenes.
- Apogeo y separación: El CanSat se separa del cohete y se despliega el paracaídas.
- Descenso: Se continúa la adquisición de datos y la transmisión de telemetría en tiempo real hacia la estación terrena.
- Aterrizaje y recuperación: Se localiza y recupera el CanSat (prioridad: recuperar la MicroSD intacta).
- Procesamiento de datos: Se descargan los datos de la MicroSD y de la telemetría para su análisis y presentación.

Roles y responsabilidades en la operación de la misión:

Integrante | Responsabilidades
Hernández, Azul | Procesamiento de Datos
Agostinelli, Nefíah | Supervisor y Coordinación
Iacono, Tiziano | Encendido y Mantenimiento (Si por urgencia es necesario)
García, Ian | Recuperamiento y Herramientas
Zamudio, Román | Telemetría (Comunicación con estación Terrena)

## PRESUPUESTO Y CAPACIDADES (6) H1

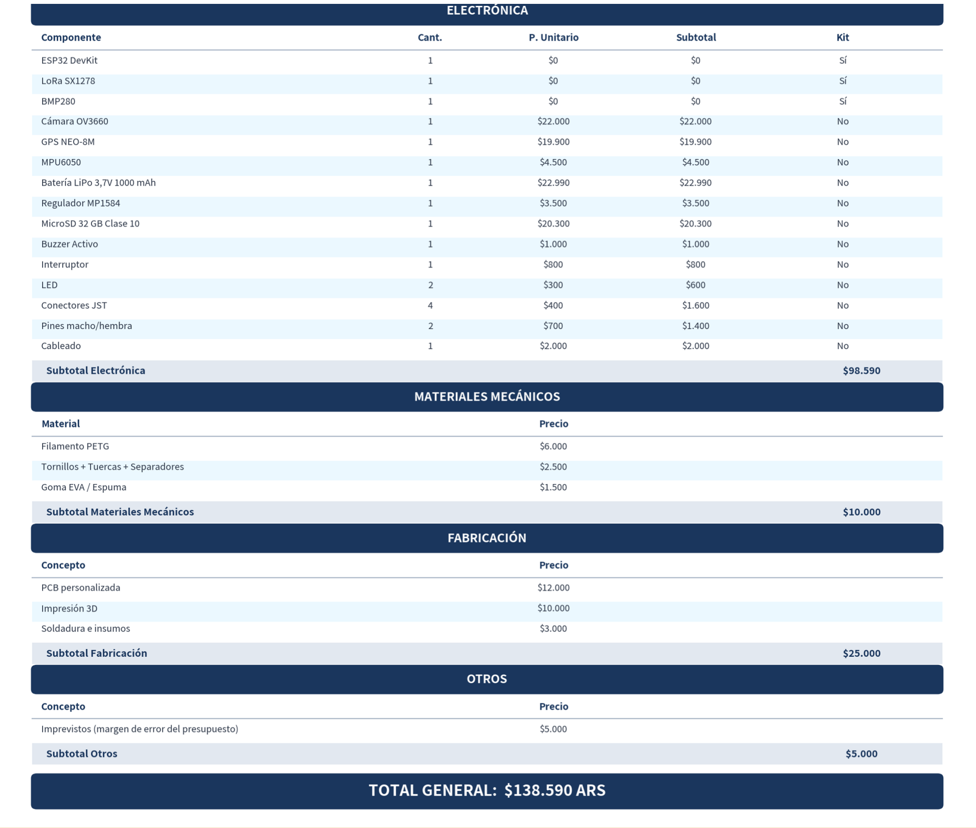
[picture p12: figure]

PRESUPUESTO

## PRESUPUESTO Y CAPACIDADES (6) H2

CAPACIDADES

La construcción del CanSat puede realizarse completamente en las instalaciones de nuestra Escuela Técnica. Contamos con impresoras 3D, herramientas de electrónica, estación de soldadura y espacio adecuado para el armado y las pruebas del prototipo.

En la especialidad de Electrónica se desarrollan competencias directamente aplicables a la misión:
- Diseño e impresión 3D
- Uso y calibración de sensores
- Soldadura y armado de circuitos
- Diseño de PCB
- Programación de microcontroladores (ESP32)
- Conocimientos generales de electrónica

Estas capacidades técnicas y materiales, junto con el acompañamiento del docente tutor, permiten desarrollar el proyecto de forma autónoma.

## AGENDA (6) H1

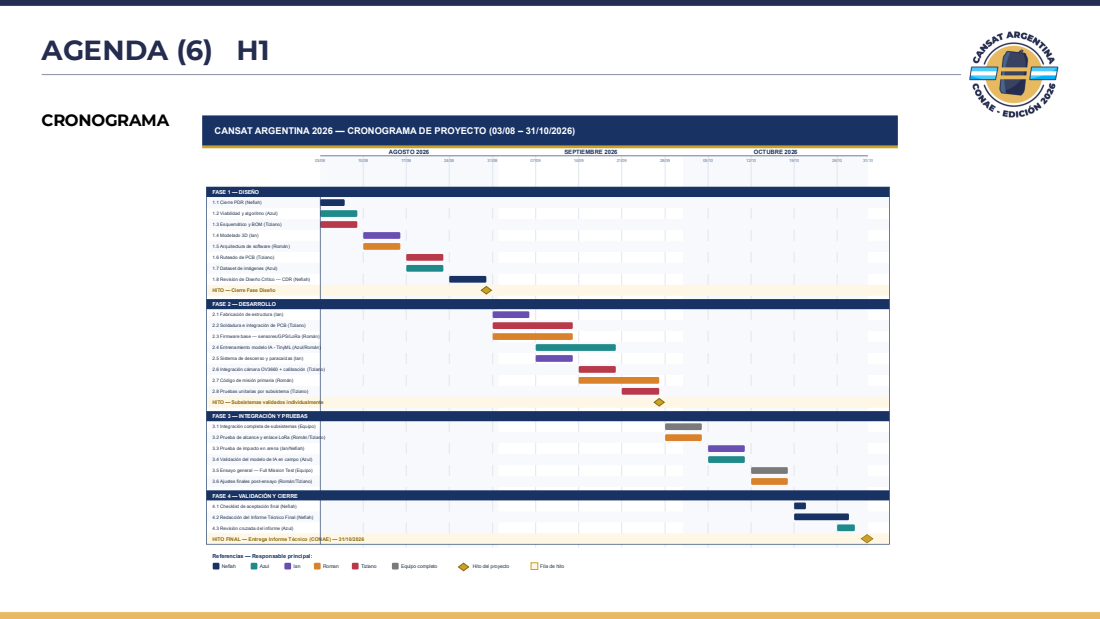
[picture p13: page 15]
CRONOGRAMA

## AGENDA (6) H2

PLAN DE DOCUMENTACIÓN
Vamos a tener una bitácora cada uno, en ella vamos a anotar observaciones e hitos.
Posteriormente vamos a procesar las bitácoras y transformarlo en un solo documento para tener un seguimiento tanto de cosas buenas como errores nuestros; El objetivo es aprender de esta experiencia.
(PD: La bitácora tendrá inclusive hora exacta).
Vamos a grabar las partes más importantes y algunas filmaciones para un video de avances que será subido a nuestro canal de YouTube.

PLAN DE PUBLICACIÓN Y DIFUSIÓN DE RESULTADOS
Nuestro plan se basa en recopilar lo que hemos grabado y filmado, con el fin de publicarlo en nuestras redes sociales (TikTok, Instagram y YouTube).
Nuestra forma de operar en esto será publicando Videos Largos y Shorts en YouTube, Reels y Publicaciones en Instagram, y por último videos cortos en TikTok.
Si llegamos a alguna instancia superior, hablaremos con los medios locales (mardelplataweb, ahoramardelplata, y canales de televisión) para difundir el proyecto y darle relevancia al menos local.
También pretendemos mostrar el proyecto en diversas exposiciones y ferias de ciencias con el fin de ampliar la difusión.

## VIDEO (15)

Link del Video de Youtube: https://www.youtube.com/watch?v=Su3cJAWn1FQ

### SI DEJA DE FUNCIONAR:

Link del Canal de Youtube: https://www.youtube.com/channel/UCQh-hTfBR6eJMSd3XWANxJg

Link del Canal de Youtube (respaldo): https://www.youtube.com/@ANTIRCanSat
Canal: @ANTIRCanSat

Extra:
Tiktok: @antircansat | https://www.tiktok.com/@antircansat
Instagram: @a.n.t.i.r | https://www.instagram.com/a.n.t.i.r/

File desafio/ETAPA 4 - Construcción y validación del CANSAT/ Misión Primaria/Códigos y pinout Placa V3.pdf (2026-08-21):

# Instalación y funcionamiento para la Misión Primaria

# CERTAMEN CANSAT 2026

# Placa Heltec ESP32 + Lora V3.2

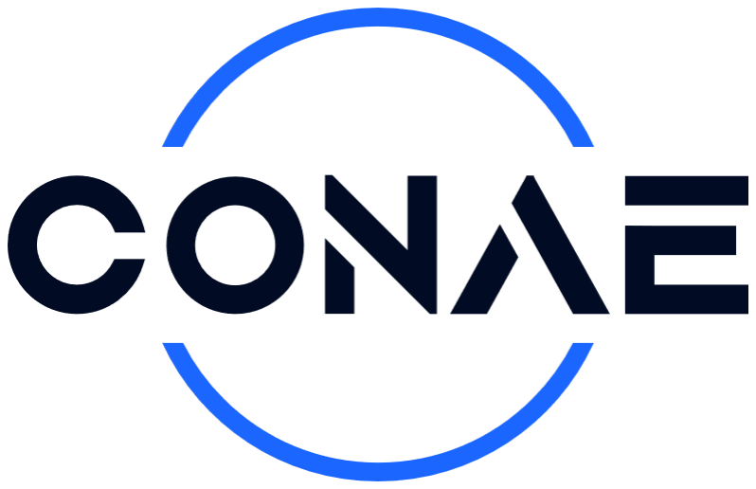
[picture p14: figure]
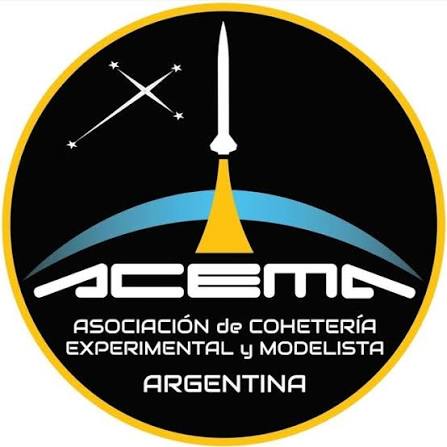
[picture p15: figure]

La Agencia Espacial Argentina

- Microprocesador: ESP32-S3FN8 (procesador

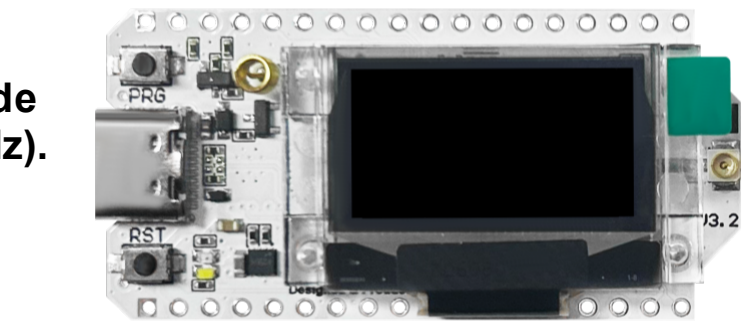
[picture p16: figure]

Xtensa® LX7 de 32 bits y doble núcleo, arquitectura de pipeline de cinco etapas, frecuencia de hasta 240 MHz).
- Chip LoRa SX1262.
- Interfaz USB Tipo-C con regulador de voltaje completo, protección ESD, protección contra
cortocircuitos, blindaje de RF y otras medidas de
protección.
- Interfaz de batería SH1.25-2 integrada y sistema de gestión de batería de litio (gestión de carga y descarga, protección contra sobrecarga, detección de nivel de batería, conmutación automática entre alimentación USB y batería).
- Pantalla OLED de matriz de puntos de 0,96 pulgadas (128x64) integrada para mostrar información de depuración, nivel de batería y otros datos.
- Conectividad integrada para tres redes (WiFi, LoRa y Bluetooth); incluye antena de resorte metálico dedicada de 2,4 GHz para Wi-Fi y Bluetooth, e interfaz IPEX (U.FL) reservada para LoRa.
- Chip CP2102 (conversor USB a serie) integrado, que facilita la carga de programas y la visualización de información de depuración.
- Compatible con el entorno de desarrollo Arduino.
- Diseño optimizado de circuitos de RF y bajo consumo de energía.

Información adicional en:
https://heltec.org/project/wifi-lora-32/

PASOS PARA LA INSTALACIÓN Y CONFIGURACIÓN DEL ENTRONO DE DESARROLLO ARDUINO

Descarga e instalación de Arduino IDE

Descargar el archivo de: https://www.arduino.cc/en/software/#ide
Instalar el software con privilegios de administrador:

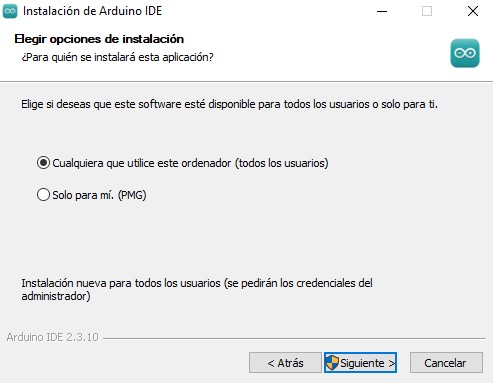
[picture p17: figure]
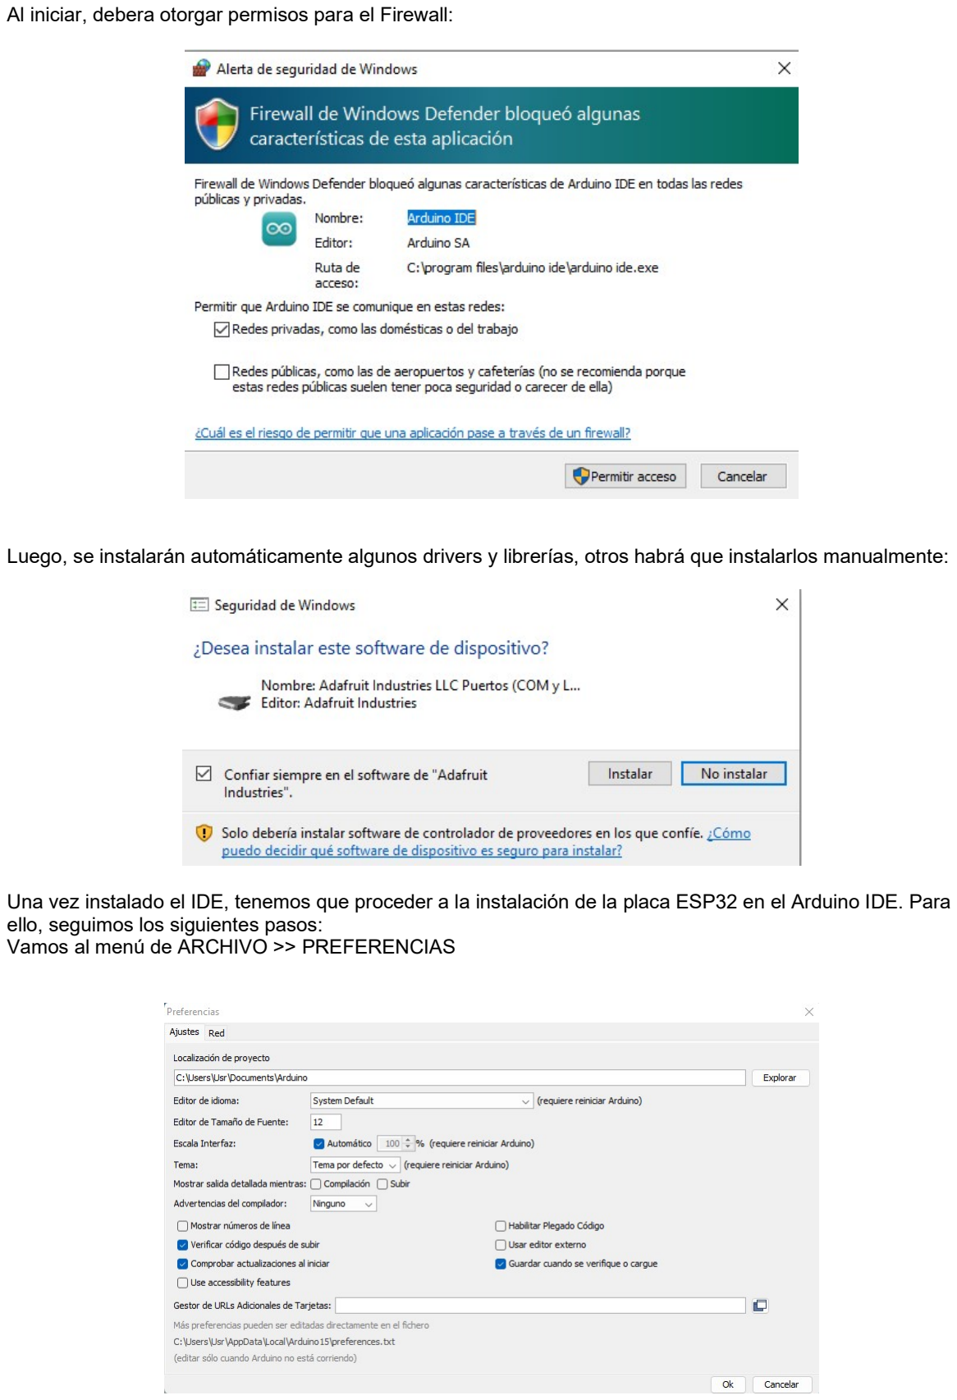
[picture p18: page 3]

Al iniciar, debera otorgar permisos para el Firewall:

Luego, se instalarán automáticamente algunos drivers y librerías, otros habrá que instalarlos manualmente:

Una vez instalado el IDE, tenemos que proceder a la instalación de la placa ESP32 en el Arduino IDE. Para ello, seguimos los siguientes pasos:
Vamos al menú de ARCHIVO >> PREFERENCIAS

En la casilla de gestor de URLs agregar:

https://github.com/Heltec-Aaron-Lee/WiFi_Kit_series/releases/download/0.0.7/package_heltec_esp32_index.json

Luego, en el board manager, seleccionar:

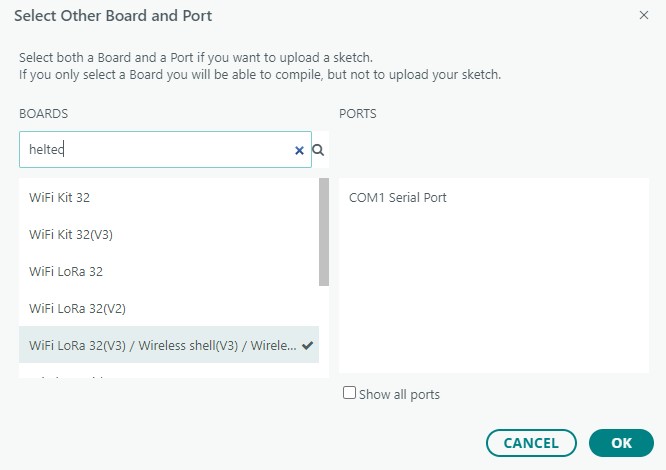
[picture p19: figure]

Instalar la siguiente librería:

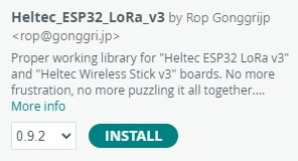
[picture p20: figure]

Y las correspondientes a ADAFRUIT BMP280, además de las que necesiten incorporar a su proyecto.

Cuando se conecte la placa, tal vez necesite los drivers para que genere un puerto COM. Los drivers pueden descargarse de:

https://resource.heltec.cn/download/tools/CP210x_Universal_Windows_Driver.zip

con todo listo, podemos cargar los códigos RX y TX:

/*********
Receptor RX Oficial para Heltec WiFi LoRa 32 V3 Usa RadioLib para el chip SX1262
*********/

#include <RadioLib.h>

#include <SPI.h>

char Version[] = "v3.0 RX - Heltec V3";

// Definición de pines para Heltec V3 (SX1262) #define HELTEC_NSS 8
#define HELTEC_DIO1 14

#define HELTEC_RST 12

#define HELTEC_BUSY 13

#define LED | 35

#define VEXT_PIN | 36

// Instancia del módulo LoRa SX1262
SX1262 radio = new Module(HELTEC_NSS, HELTEC_DIO1, HELTEC_RST, HELTEC_BUSY);

#define SERIAL_BAUDRATE 115200

// Configuraciones del módulo LoRa
#define LORA_FREQUENCY | 915.0 | // MHz

#define LORA_BANDWIDTH | 125.0 | // kHz

#define LORA_SPREAD_FACTOR 7 #define LORA_CODING_RATE 5

#define LORA_SYNC_WORD 0xF3

void setup() {
// Activar alimentación externa (Vext) pinMode(VEXT_PIN, OUTPUT); digitalWrite(VEXT_PIN, LOW); delay(100);

pinMode(LED, OUTPUT);
digitalWrite(LED, HIGH);

Serial.begin(SERIAL_BAUDRATE);
delay(1000);

Serial.println("\n--- Inicializando Receptor LoRa SX1262 (Heltec V3) ---");

// Inicialización de RadioLib
int state = radio.begin(LORA_FREQUENCY, LORA_BANDWIDTH, LORA_SPREAD_FACTOR, LORA_CODING_RATE, LORA_SYNC_WORD);

if (state == RADIOLIB_ERR_NONE) {
Serial.println("¡LoRa RX Inicializado Correctamente!");
digitalWrite(LED, LOW);
} else {
Serial.print("Error al iniciar LoRa, código: "); Serial.println(state);
while (true) {
digitalWrite(LED, !digitalRead(LED)); delay(200);
}
}
}

void loop() {
String strData;
int state = radio.receive(strData);

if (state == RADIOLIB_ERR_NONE) { digitalWrite(LED, HIGH);

Serial.print("RX - Version "); Serial.println(Version);

Serial.print("Telemetria RAW Recibida: "); Serial.println(strData);

// Parseo de los datos separados por comas
int indicador1 = strData.indexOf(',');
String pktNumber = strData.substring(0, indicador1); Serial.print("Packet Number: ");
Serial.println(pktNumber);

int indicador2 = strData.indexOf(',', indicador1 + 1);
String presionBase = strData.substring(indicador1 + 1, indicador2); Serial.print("Presion Base: ");
Serial.println(presionBase);

int indicador3 = strData.indexOf(',', indicador2 + 1);
String presionAbsoluta = strData.substring(indicador2 + 1, indicador3); Serial.print("Presion Absoluta: ");
Serial.println(presionAbsoluta);

int indicador4 = strData.indexOf(',', indicador3 + 1);
String altura = strData.substring(indicador3 + 1, indicador4); Serial.print("Altura: ");
Serial.println(altura);

int indicador5 = strData.indexOf(',', indicador4 + 1);
String temperatura = strData.substring(indicador4 + 1, indicador5); Serial.print("Temperatura: ");
Serial.println(temperatura);

// RSSI y SNR del paquete recibido
Serial.print("Nivel de señal [RSSI]: "); Serial.print(radio.getRSSI()); Serial.println(" dBm");

Serial.print("Relación Señal/Ruido [SNR]: ");
Serial.print(radio.getSNR());
Serial.println(" dB");

Serial.println("====================================================================="); digitalWrite(LED, LOW);
}
}

/*
Transmisor TX Oficial para Heltec WiFi LoRa 32 V3 + BMP280 */

#include <RadioLib.h>

#include <Wire.h>

#include <Adafruit_BMP280.h> // Librería para BMP280

char Version[] = "v3.0 BMP280 - Heltec V3";

#define HELTEC_NSS 8

#define HELTEC_DIO1 14

#define HELTEC_RST 12

#define HELTEC_BUSY 13

#define LED | 35

#define VEXT_PIN | 36

#define I2C_SDA | 41

#define I2C_SCL | 42

SX1262 radio = new Module(HELTEC_NSS, HELTEC_DIO1, HELTEC_RST, HELTEC_BUSY); Adafruit_BMP280 bmp; // Objeto BMP280

#define SERIAL_BAUDRATE 115200

#define INTERVAL_TIME_TX 1000

#define LORA_FREQUENCY | 915.0

#define LORA_BANDWIDTH | 125.0

#define LORA_SPREAD_FACTOR 7 #define LORA_CODING_RATE 5

#define LORA_SYNC_WORD | 0xF3

#define LORA_POWER | 17

double baseline;
double T, P, A;
unsigned int pktNumber = 0;

void readTempPressure();

void setup() {
pinMode(VEXT_PIN, OUTPUT); digitalWrite(VEXT_PIN, LOW); // Alimenta I2C / Pantalla delay(100);

pinMode(LED, OUTPUT);
digitalWrite(LED, HIGH);

Serial.begin(SERIAL_BAUDRATE);
delay(1000);

Serial.println("\n--- Inicializando Transmisor (BMP280) ---");

// Inicializar LoRa
int state = radio.begin(LORA_FREQUENCY, LORA_BANDWIDTH, LORA_SPREAD_FACTOR, LORA_CODING_RATE, LORA_SYNC_WORD, LORA_POWER);

if (state == RADIOLIB_ERR_NONE) {
Serial.println("¡LoRa RadioLib OK!");
} else {

Serial.print("Error LoRa, código: "); Serial.println(state);
while (true);
}

// Inicializar I2C
Wire.begin(I2C_SDA, I2C_SCL); bool bmpIsInit = false;

do {
delay(1000);
// Probamos primero con dirección 0x76 (típica del BMP280) y luego 0x77 if (bmp.begin(0x76) || bmp.begin(0x77)) {
Serial.println("¡BMP280 encontrado e iniciado OK!"); readTempPressure();
baseline = P;
Serial.print("Presion Base: ");
Serial.print(baseline * 0.01); Serial.println(" hpa");
bmpIsInit = true;
digitalWrite(LED, LOW);
} else {
Serial.println("Buscando BMP280 en GPIO 41/42..."); }
} while (!bmpIsInit);
}

void loop() {
readTempPressure();

pktNumber++;
if (pktNumber >= 65500) pktNumber = 0;

String packetData = String(pktNumber) + "," + String(baseline * 0.01, 2) + "," + String(P * 0.01, 2) + "," + String(A, 2) + "," +
String(T, 1);

Serial.print("TX - Version "); Serial.println(Version); Serial.print("Packet Number: "); Serial.println(pktNumber); Serial.print("Enviando: "); Serial.println(packetData);

digitalWrite(LED, HIGH);

int state = radio.transmit(packetData);

if (state == RADIOLIB_ERR_NONE) { Serial.println("Paquete enviado con éxito."); } else {
Serial.print("Error al transmitir: "); Serial.println(state);
}

digitalWrite(LED, LOW);
Serial.println("=====================================================================");

delay(INTERVAL_TIME_TX);
}

void readTempPressure() {

T = bmp.readTemperature();
P = bmp.readPressure();
A = bmp.readAltitude(1013.25); // Presión promedio a nivel del mar }

Compìlar y cargar ambas placas con el código.

Hardware - Diagrama de conexionado

El conexionado entre el módulo BMP280 y el ESP32, requiere solo de 4 cables:

BMP280 | Heltec LORA ESP32 (V2)
VCC | 3V3
GND | GND
SCL (Clock) | GPIO 42
SDA (Data) | GPIO 41

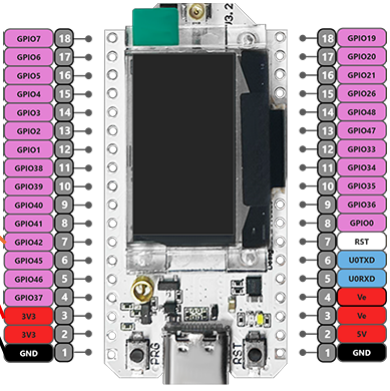
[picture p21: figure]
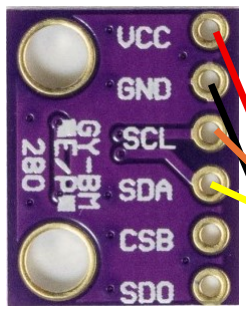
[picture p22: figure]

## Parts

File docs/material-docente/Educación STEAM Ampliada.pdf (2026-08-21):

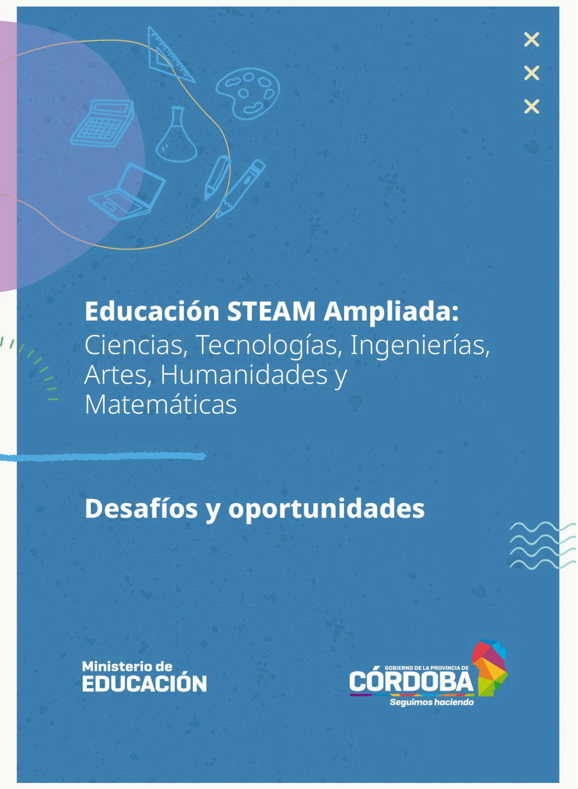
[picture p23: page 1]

| Educación STEAM Ampliada |

## Contenido

01. Presentación | 3
02. Acerca de la Educación STEAM Ampliada | 5

### 03. Construcción, profundización, conexión y resignificación de saberes en la

Educación STEAM Ampliada | 11
3.1. Ejemplos de abordajes interdisciplinarios y multidisciplinarios | 15

### 04. El proyecto: formato pedagógico privilegiado en la Educación

STEAM Ampliada | 20
4.1. La importancia de las preguntas | 22
4.1.1. Ejemplos para el abordaje de preguntas | 25
4.2. Los productos | 28
4.2.1. Ejemplos para la definición de productos | 29
4.3. Las acciones | 31

### 4.3.1. Orientaciones/acciones para el diseño de proyectos en el marco

de la Educación STEAM Ampliada | 35

### 4.4. Un escenario en movimiento: sobre los tiempos y espacios en los

proyectos de la Educación STEAM Ampliada | 37
4.5. Prácticas de evaluación en los proyectos de Educación STEAM Ampliada | 38
4.5.1. Los instrumentos de evaluación de proyectos | 39
4.5.2. Las retroalimentaciones docentes | 40
4.5.3. Los procesos metacognitivos | 41

### 05. Otros formatos pedagógicos para las propuestas de la Educación

STEAM Ampliada | 42
06. Auxiliares didácticos | 45
07. Bibliografía | 46

## Presentación

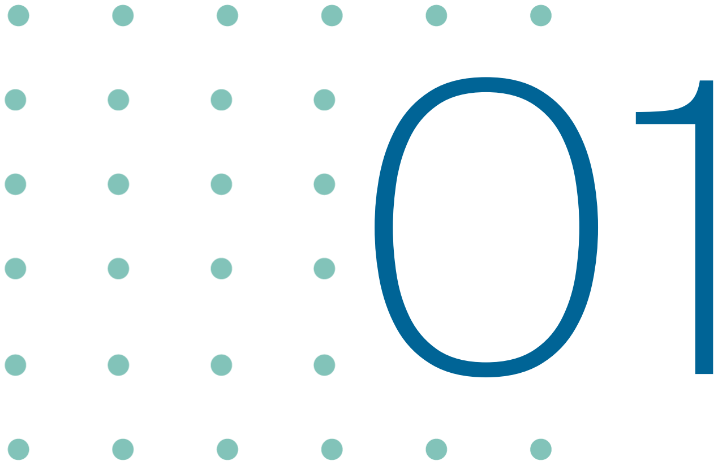
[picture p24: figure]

Cada vez más, el mundo actual demanda la proposición colectiva, activa y creativa de nuevas formas de construir el conocimiento y generar vínculos diversos con la naturaleza, las sociedades y el pensamiento. En un mundo cambiante, donde no es posible predecir cómo será el futuro que habitaremos, es fundamental desarrollar la capacidad de aprender de manera autónoma, en colaboración con otros (compartiendo iniciativas y construyendo ideas) a lo largo de la vida.

La mayor parte de los desafíos globales y locales (el calentamiento global, el acceso a la educación de calidad a lo largo de la vida, el fin de la pobreza y el hambre cero, la igualdad de género, la reducción de las desigualdades, entre otros), presentes y futuros, requieren abordajes complejos. Frente a lo contingente de la época, los y las estudiantes no solo necesitan información, sino también la capacidad de construir conocimientos, actitudes y valores, y desarrollar diversos modos de pensar.

Con esas prerrogativas, la Educación STEAM Ampliada

1
(Ciencias,
Tecnologías, Ingenierías, Artes y Humanidades, y Matemáticas) permite pensar la enseñanza desde un enfoque holístico de interacción activa con la

1 La denominación STEAM Ampliada fue acuñada en el marco del Programa PIEnsA Córdoba - Escuelas Municipales ALAS, del sistema educativo de la Municipalidad de Córdoba (Provincia de Córdoba, Argentina), (Diseño e implementación: 2020-2021).

comunidad de pertenencia y el mundo, para explicarlo, comprenderlo e intervenir en él.

Como propuesta, la Educación STEAM Ampliada no solo es una herramienta para comprender el mundo, sino también para dar forma a un futuro mejor. Es la invitación hacia una educación transformadora en la que estudiantes, docentes y comunidades educativas se embarcan en un viaje conjunto de descubrimiento y aprendizaje; un viaje cuyo horizonte es la ESCUELA POSIBLE

2
, en tanto institución educativa con capacidad para resignificarse y evolucionar, en tránsito constante hacia la mejora continua en contexto. Es decir, la Educación STEAM Ampliada es una apuesta efectiva por “la escuela inteligente, sensible y emprendedora” (Córdoba. Ministerio de Educación, 2023a, p. 1).

En línea con lo anterior, el presente documento incluye una aproximación a la Educación STEAM Ampliada desde la perspectiva del sistema educativo de la provincia de Córdoba. Su objetivo es proporcionar orientaciones sobre su implementación en la enseñanza en la Educación Inicial, Primaria, Secundaria, Superior y modalidades. Constituye, entonces, un instrumento conceptual y metodológico destinado a acompañar la exploración cotidiana que se realiza al diseñar, implementar y evaluar propuestas de enseñanza. Acerca un conjunto de reflexiones, preguntas, recursos, ejemplos y aportes para la construcción de propuestas didácticas bajo la Educación STEAM Ampliada en un recorrido que puede ser resignificado por cada docente en función de decisiones situadas, experiencias y saberes, desde la Educación Inicial hasta la Educación Superior.

2 La Escuela Posible brinda el marco para las acciones institucionales en el Sistema Educativo de Córdoba. La lectura del documento La Escuela Posible: consolida logros y emprende la mejora (Córdoba. Ministerio de Educación, 2024b) puede hacerse en el siguiente enlace: https://www.igualdadycalidadcba.gov.ar/SIPEC-CBA/publicaciones/2024/Ministerio-de-Educacion_La-Escuela-Posible.pdf (https://www.igualdadycalidadcba.gov.ar/SIPEC-CBA/publicaciones/2024/Ministerio-de-Educacion_La-Escuela-Posible.pdf)

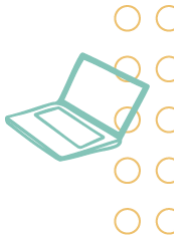
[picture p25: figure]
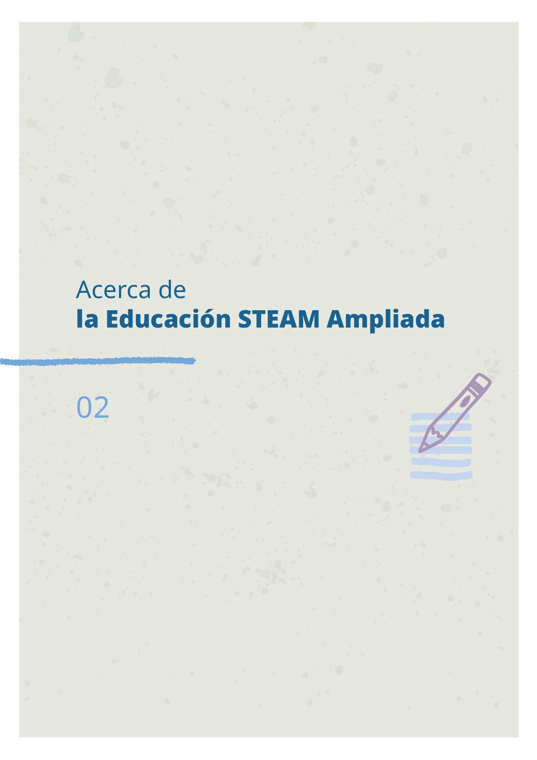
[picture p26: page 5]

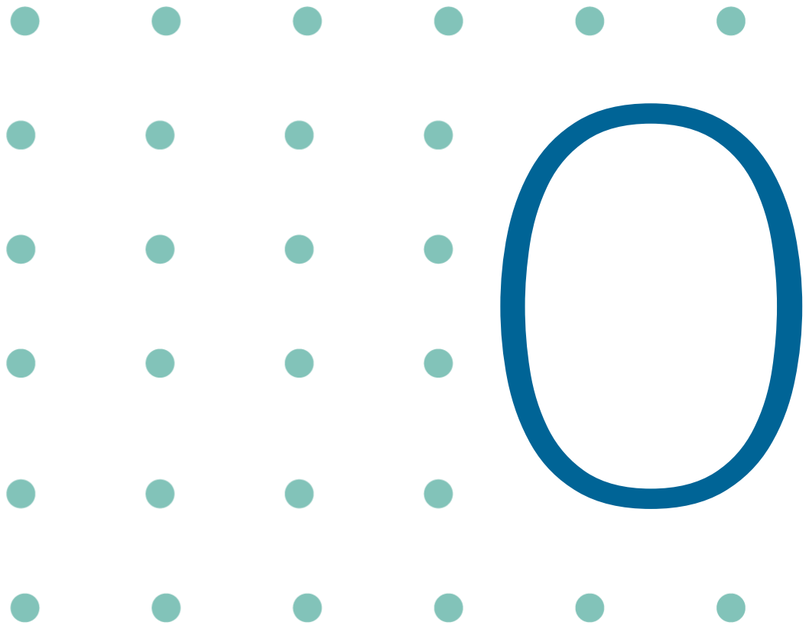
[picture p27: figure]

02

## Acerca de la Educación STEAM Ampliada

Cuando dejamos que los niños experimenten, tomen riesgos y jueguen con sus propias ideas, les permitimos confiar en sí mismos. Así, comienzan a verse a sí mismos como estudiantes que tienen buenas ideas y que pueden transformar sus propias ideas en realidad. Cuando admitimos que puede haber muchas respuestas correctas a una pregunta, permitimos que el niño se sienta seguro al pensar y resolver problemas. (Libow Martínez y Stager, 2019, p. 68)

La Educación STEAM Ampliada convoca a aprender desde la curiosidad, la exploración y la búsqueda permanente de preguntas y respuestas. Sus raíces están en las propuestas STEM (Ciencia, Tecnología, Ingeniería, Matemáticas, del inglés Science, Technology, Engineering, Mathematics) que surgieron en la década de los 90 desde la Fundación Nacional para la Ciencia de los Estados Unidos

3
. El objetivo fundamental de la iniciativa fue el fortalecimiento de las vocaciones científicas y tecnológicas a partir de la prioridad de la enseñanza de las ciencias, las tecnologías, las ingenierías y las matemáticas. Para su implementación, se involucraron tanto actores de ámbitos universitarios como de distintos sectores públicos y políticos.

3 La Fundación Nacional de Ciencias (NSF, sigla en inglés) promueve el progreso en las ciencias y las matemáticas, y es responsable de facilitar la investigación en la ciencia y la ingeniería para
promover | las | innovaciones científicas. Ver sitio en el siguiente enlace:
https://www.usa.gov/es/agencias/fundacion-nacional-de-ciencias

Las diversas experiencias que se desarrollaron impactaron en el ámbito educativo formal y generaron transformaciones en las metodologías de enseñanza promotoras de un aprendizaje en el que el estudiante tiene un rol activo. A su vez, con el tiempo, se incluyeron otras disciplinas, como artes, lo que posibilitó nuevas miradas. La reflexión y las reformas se instalaron en todos los niveles de educación y comenzó a hablarse de Educación STEM/STEAM Integrada o i-STEAM (Kelley & Knowles, 2016).

A la fecha, numerosos países y organizaciones de todo el mundo desarrollan programas y currículos que se relacionan con este enfoque que integra ciencias, tecnología, ingeniería y matemáticas. A su vez, un número cada vez mayor de publicaciones y programas suman la letra “A” al acróstico en referencia a la inclusión del arte, así como otros la “H” en relación con las humanidades o la “C” para la cultura. En la práctica, se puede integrar cualquier otra disciplina a STEM, sin por eso tener que modificar la sigla. Sin embargo, en la actualidad se elige la denominación STEAM para enfatizar la incorporación del arte y las humanidades en este abordaje.

Mención especial requiere el sentido de la letra “E”, que en el STEM/STEAM implica la ingeniería. Sus orígenes se vinculan con la educación universitaria y el sentido de propiciar e incentivar el estudio de sus diversas ramas: química, electrónica, industrial, etcétera. En la educación obligatoria, la “E” se vincula con el pensamiento ingenieril, es decir, un tipo de pensamiento que colabora en la resolución de situaciones problemáticas a partir de prácticas sistemáticas de diseño. Pero también, con la manipulación de objetos, con la experiencia directa, la experimentación y el descubrimiento.

Por nuestra parte, cuando hablamos de Educación STEAM Ampliada hacemos referencia a la articulación de dos o más campos del conocimiento / espacios curriculares / unidades curriculares vinculados

4 con ciencias,
tecnologías, ingenierías, artes, humanidades y matemáticas, dentro de un contexto auténtico con el propósito de conectarlos de manera genuina para mejorar el aprendizaje de los y las estudiantes.

### 4 La distinción marca las diferentes denominaciones de los distintos campos de saber

disciplinar según el nivel educativo: campo de conocimiento para Educación Inicial; espacios curriculares para Educación Primaria y Secundaria; y unidades curriculares para Educación Superior.

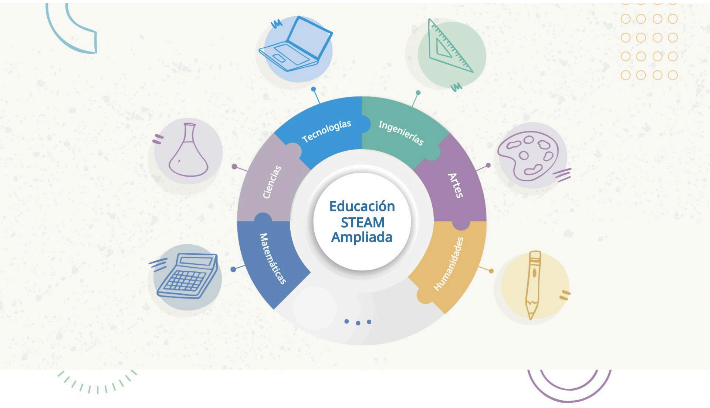
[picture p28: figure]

Las propuestas didácticas, desde esta perspectiva, tienen como principal objetivo habilitar nuevos y diversos tiempos, y espacios de enseñanza y aprendizaje para la construcción, profundización, conexión y resignificación de saberes de distintas áreas del conocimiento y el desarrollo de capacidades fundamentales

### 5 desde su carácter integral e

integrador, para la vida presente y futura.

De este modo, las propuestas didácticas desde la Educación STEAM Ampliada asumen pedagógicamente el abordaje de un tema o problema real y complejo del mundo natural, social, tecnológico, económico, político, superando tanto la fragmentación y la atomización de contenidos como la acumulación excesiva de información, sin descuido del saber disciplinar como

5 Oralidad, lectura y escritura; Anticipación y resolución de situaciones problemáticas; Pensamiento crítico; Creatividad; Trabajo colaborativo y cooperativo; Gestión y monitoreo del propio aprendizaje; Compromiso, responsabilidad e iniciativa; Ciudadanía local, global y digital. (Córdoba. Ministerio de Educación, 2024a).

puerta de acceso a la comprensión de los procesos complejos y dinámicos del mundo en que vivimos. Asimismo, estas propuestas favorecen el desarrollo de las capacidades fundamentales, por un lado, porque se articulan con los contenidos que se integran en tanto resultan, necesariamente, asociadas con el currículum; por el otro, porque se les ofrecen a los estudiantes situaciones en las que se ponen en juego tanto el “saber” como el “saber hacer”. Después de todo, “la idea de la enseñanza y el aprendizaje STEM es favorecer la motivación de los estudiantes, profundizar su comprensión, aumentar sus logros y ayudarlos a ver la relevancia de lo que están aprendiendo" (Vasquez et al., 2013, p. 59).

Vale decir, entonces, que las propuestas didácticas desde la Educación STEAM Ampliada se caracterizan por:

⬝ involucrar temas o problemas relevantes y significativos para los y las estudiantes y sus comunidades;
⬝ propiciar la construcción, profundización, conexión y resignificación de saberes de distintas áreas del conocimiento, para favorecer la comprensión mediante la articulación de contenidos y modos de conocer de campos del conocimiento / espacios curriculares / unidades curriculares diversos;
⬝ favorecer el desarrollo de las capacidades fundamentales a partir de experiencias educativas que posibilitan diferentes maneras de apropiación del conocimiento;
⬝ promover el logro de productos fruto de las resoluciones de “desafíos” que implican un aprendizaje activo y comprometido; ⬝ promover diversos agrupamientos entre docentes y entre estudiantes, y nuevas oportunidades de organizar el tiempo y espacio dentro y fuera de la sala/aula/curso.

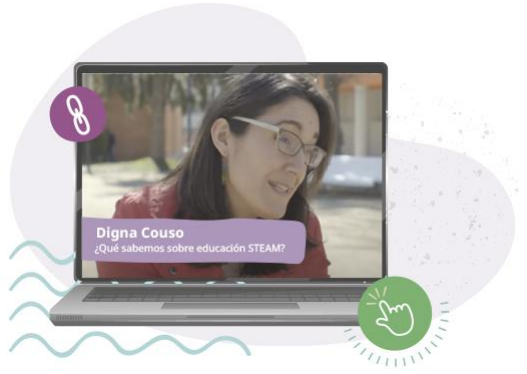
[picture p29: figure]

Clic aquí (https://www.youtube.com/watch?v=q05yduPaZVY) para ver el video.

En el video Hablamos con Digna Couso. ¿Qué sabemos sobre la educación STEAM? (EduCaixaTV, 2019), la investigadora y educadora reflexiona sobre el enfoque STEAM.

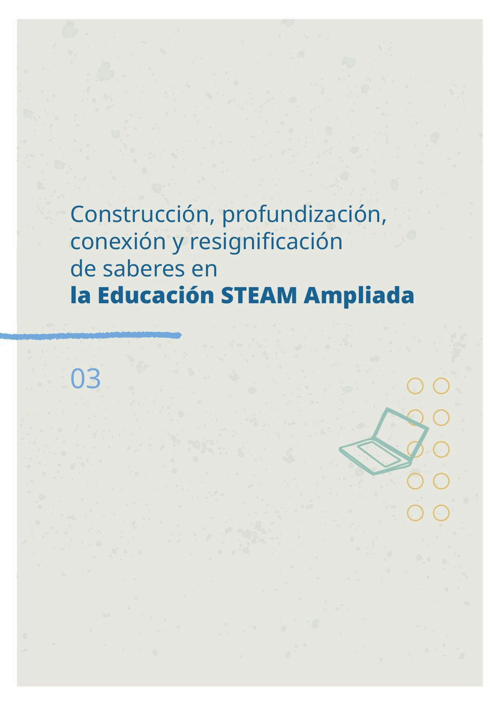
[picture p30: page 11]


03

Construcción, profundización,

## conexión y resignificación de saberes en la Educación STEAM Ampliada

Planificar, implementar y evaluar propuestas didácticas desde la Educación STEAM Ampliada implica reorientar la lógica desde la cual se diseñan las propuestas de enseñanza. El desafío es lograr recortes que permitan el diálogo de contenidos articulados entre dos o más campos del conocimiento / espacios curriculares / unidades curriculares. Para ello, se requiere profundizar en los procesos de apropiación curricular en contexto y redefinir institucionalmente los modos de pensar la enseñanza y el aprendizaje (Córdoba. Ministerio de Educación, 2018). En ese sentido, las propuestas podrán organizarse:

6

⬝ Desde la interdisciplina, donde se planifica una propuesta didáctica entre dos o más campos de conocimiento / espacios curriculares / unidades didácticas en la cual se integran saberes. En este caso, los objetivos de aprendizaje de la propuesta didáctica deben demostrar cómo esos campos del conocimiento / espacios curriculares / unidades curriculares conforman un saber integrado. En este marco, Boix Mansilla et al. (2018) sostienen que “las personas demuestran comprensión interdisciplinaria cuando

6 Otra forma valiosa de organizar las propuestas didácticas no se desarrolla aquí, pero se puede considerar al momento de planificar, por ejemplo, la transdisciplina.

integran conocimientos y modos de pensar de dos o más disciplinas para crear productos, plantear interrogantes, solucionar problemas y dar explicaciones al mundo que los rodea de un modo que no hubiera sido posible mediante una sola disciplina” (p. 18). En la provincia de Córdoba, las Jornadas de Integración de Saberes en la Educación Secundaria son un ejemplo de este estilo de abordaje (Córdoba. Ministerio de Educación, 2018).



Clic aquí (https://youtu.be/euyRWRZmdtA?si=FEEbQ8UaFjihPFVX) para ver el video.

En el video, la Dra. Verónica Boix Mansilla —investigadora principal del Proyecto Zero en la Universidad de Harvard— reflexiona en torno al interrogante: ¿Qué es la comprensión interdisciplinaria y por qué es importante en la actualidad? (Organización de Estados Iberoamericanos OEI, 2019).

⬝ Desde la multidisciplina, donde se planifican propuestas didácticas desde diferentes campos de conocimiento / espacios curriculares / unidades didácticas que abordan un tema en común para facilitar la construcción de conocimiento en torno a esa temática a partir del aporte de múltiples miradas y perspectivas. La selección del tema es fundamental: se deben considerar aquellos cuya naturaleza multidisciplinar involucra y conecta contenidos, metodologías y enfoques de diferentes áreas.


## 3.1. Ejemplos de abordajes interdisciplinarios y multidisciplinarios

Se presentan, a continuación, ejemplos de proyectos abordados en cada caso desde la interdisciplinariedad y la multidisciplinariedad.

### Desde la interdisciplina

### | Ejemplo 1 |

A partir de la pregunta por cómo medir el impacto que ha tenido la tecnología GPS en el traslado de los ciudadanos y las ciudadanas, se deriva un proyecto que integra saberes de los espacios curriculares Ciencias Sociales-Geografía, Matemáticas, Ciudadanía y Participación, y Educación Tecnológica en Educación Secundaria.

La mayoría de los estudiantes de la escuela viven en barrios o comunidades distantes, por lo que el proyecto "Optimización de rutas escolares con tecnología GPS" tiene como objetivo elaborar un mapa de optimización de tiempo, energética, económica, seguridad, etcétera, de las rutas de traslado de los y las estudiantes a la escuela.

El proyecto involucra múltiples saberes y actividades que se construyen entre los espacios curriculares, por ejemplo: indagan sobre el funcionamiento de la tecnología GPS y cómo se utiliza para la planificación de rutas de traslado mediante la familiarización con aplicaciones como Google Maps. Elaboran sus propios recorridos, identifican necesidades y desafíos en los traslados diarios de los estudiantes a través de encuestas (a sus familias y personas de la comunidad educativa, entre otros) con foco en normas y criterios de tránsito para la circulación autónoma y segura. Recuperan información sobre las condiciones del tráfico y rutas próximas a la escuela e identifican factores que influyen en la problemática del tránsito. Simulan y comparan las rutas optimizadas con las rutas tradicionales, realizan pruebas pilotos de los recorridos y analizan los datos y resultados, calculan y evalúan ahorros de tiempo, energéticos, económicos, impactos ambientales y otros, comunican los procesos y resultados, y reflexionan sobre sus propios aprendizajes. Pueden incluso desarrollar un sistema de optimización mediante un software o una aplicación.

### | Ejemplo 2 |

Un grupo de estudiantes de Educación Primaria encontró un nido de hornero y lo llevó al aula. Comenzó allí una aventura del conocimiento a través de un proyecto que surge de sus intereses: les importa, los involucra y se sienten motivados.

Realizan una serie de actividades tales como mediciones, pesaje de nidos, análisis de las formas y materiales usados para la construcción y creación de modelos con impresoras 3D de las estructuras. También, envían formularios de Google a la comunidad local para identificar la ubicación de los nidos y exploran textos en inglés relacionados con la indagación que llevan a cabo.

7

Este proyecto interdisciplinario contempla aprendizajes de los
espacios | Ciencias | Naturales, | Ciencias | Sociales, | Lengua
Extranjera-Inglés y Educación Tecnológica. Este proyecto, con las adaptaciones de recursos, aprendizajes y saberes necesarios, bien puede realizarse también en un plurigrado de la modalidad Rural e incluso en otro nivel, como el Inicial.

7 Este ejemplo se retoma de la experiencia realizada en la Escuela Municipal Santiago del Castillo de la Ciudad de Córdoba Capital. En el siguiente enlace es posible conocer más detalles: https://youtu.be/vSEja2OyaJE?si=ySgT3as6mUjzGghH

### Desde la multidisciplina

### | Ejemplo 1 |

La propuesta didáctica en torno al tema “Biometría y condiciones físicas y motrices de deportistas argentinos/as” se planifica desde el espacio curricular Educación Física y en articulación con saberes de Matemática y Educación Tecnológica en Educación Primaria.

La docente de Educación Física abordará prácticas corporales y ludomotrices que requieran la identificación de las capacidades motoras como, por ejemplo, la resistencia aeróbica en intervalos breves, la velocidad, etcétera. Los y las estudiantes construyen fichas técnicas de deportistas locales y de ellos mismos a partir de mediciones antropométricas (altura, pulso, talle, etcétera).

La propuesta didáctica requiere el abordaje de determinados saberes de otros espacios curriculares. Desde Matemáticas, se aborda previamente la medición además de aspectos vinculados a la sistematización de la información para que puedan utilizar esos saberes en la elaboración de las fichas. Desde Educación Tecnológica, se permitirá la exploración de tecnologías de seguimiento de las condiciones físicas presentes, a través de cronómetros, relojes inteligentes o aplicaciones móviles, etcétera, que luego utilizarán para realizar las mediciones.

### | Ejemplo 2 |

En la Educación Superior, en el marco del Campo de la Formación Específica-Taller de Ciencias en la Escuela, se propone a los estudiantes el abordaje del concepto “soberanía alimentaria” mediante el diseño de un taller para estudiantes del 2.° Ciclo de la Educación Primaria. La selección y el abordaje de esta temática requiere de saberes específicos y permite una propuesta didáctica epistemológica y metodológicamente fortalecida a partir del trabajo con contenidos previamente abordados por las asignaturas Ciencias Naturales y sus Didáctica I y II, Ciencias Sociales y sus Didáctica I y II; y Ética y Construcción de Ciudadanía.

8

8 Este ejemplo está inspirado en la propuesta del itinerario pedagógico didáctico Taller de Ciencias en la
escuela | (ProFoDI-MC., | s. | f.) | cuya | lectura | se | puede | realizar | en
https://dges-cba.edu.ar/wp/wp-content/uploads/2023/10/07_CFE-TALLER_DE_CIENCIAS_EN_LA_ESCUELA-_3ro_PRIMARIA.pdf (https://dges-cba.edu.ar/wp/wp-content/uploads/2023/10/07_CFE-TALLER_DE_CIENCIAS_EN_LA_ESCUELA-_3ro_PRIMARIA.pdf)



04

## El proyecto: formato pedagógico privilegiado en la Educación STEAM Ampliada

Los proyectos en el ámbito educativo son experiencias poderosas para experimentar nuevos modos de vivir la escuela. Son portadores de sentido y despiertan ganas de comprender el mundo y actuar en él. Los proyectos como modalidad organizativa implican un conjunto de acciones (diseño, desarrollo y evaluación) orientadas a alcanzar un producto que constituirá la respuesta a una pregunta inicial, una necesidad o una problemática.

Considerando el proyecto en tanto formato pedagógico privilegiado para las propuestas de la Educación STEAM Ampliada, se espera:

⬝ que sea importante, tanto para el o la docente como para el o la estudiante (el proyecto “me/nos importa: deseo ser parte de su realización”);
⬝ que sea compartible (“porque puedo construir saberes con otros y otras al realizarlo”);
⬝ que sea significativo a nivel personal, pero también a nivel grupo/clase/comunidad.


En relación con el desarrollo de los proyectos, se debe considerar que

para que un proyecto resulte significativo en términos de aprendizaje es necesario que los alumnos se propongan una meta, planifiquen las acciones para cumplirla, lleven adelante una diversidad de actividades, prueben y elijan caminos alternativos, recursos variados y tomen decisiones para cada uno de estos trayectos. En síntesis, es preciso que los estudiantes se involucren en un proceso de planeamiento, investigación, práctica y toma de decisiones. (Anijovich y Mora, 2017, p. 94)

Usualmente, al nombrar los proyectos se involucran tanto palabras centradas en el hacer (armamos, diseñamos, creamos, etcétera) como los productos que se espera lograr (por ejemplo, un club de lectura de libros vinculados al ambiente). En ese sentido, diseñar un proyecto involucra dos tipos de objetivos: por un lado, aquellos que se relacionan con el producto propiamente dicho y, por otro, aquellos que hacen referencia directa al logro de los aprendizajes. El desafío docente es reunirlos del mejor modo posible y poner en evidencia la integración de los saberes. Si los objetivos vinculados con el producto faltan o son débiles, el proyecto será un “como si” en el que nadie sentirá realmente que está comprometido con una meta auténtica. Si faltan los objetivos vinculados a los aprendizajes, las actividades serán divertidas y atrapantes, pero se perderá de vista la función educativa y formativa del espacio en el que se desarrollan (Furman et al., 2021).

A continuación, profundizaremos en aspectos claves de los proyectos y su planificación didáctica:

⬝ Las preguntas
⬝ Los productos
⬝ La organización de las acciones ⬝ Los tiempos y espacios
⬝ Las prácticas de evaluación

## 4.1. La importancia de las preguntas

Las preguntas en una propuesta didáctica de Educación STEAM Ampliada ocupan un lugar central. Son la vía regia para promover procesos de indagación y conectar con hechos, situaciones o problemas reales, actuales y relevantes para los y las estudiantes.

Una pregunta es la que da inicio al proyecto; sin embargo, al buscar entender y explicar los fenómenos que el proyecto explora, aparecerán otras preguntas, nuevas, distintas, por lo que será necesario, en muchas oportunidades, reformular la pregunta inicial. Las preguntas pueden tomar la forma de un desafío, de una situación problemática, de un caso. De cualquier modo, brindan las primeras “pistas” por donde comenzar a desandar el proyecto. En algunas oportunidades, esas consignas iniciales pueden colocar a los estudiantes en roles simulados de expertos o equipos de expertos, por ejemplo: un equipo formado por una meteoróloga y un ingeniero, o una antropóloga y un matemático, o médicas y músicos, etcétera.

La riqueza y potencialidad de las preguntas se encuentra en que:

⬝ Favorecen la curiosidad y la indagación. Las buenas preguntas fomentan la indagación y la exploración activa, lo que es esencial para el aprendizaje en la Educación STEAM Ampliada. Cuando los estudiantes se sienten intrigados por una pregunta, están más motivados para buscar respuestas y comprender saberes.
⬝ Surgen de temas o problemas reales, actuales y relevantes. En este sentido, es importante que las preguntas involucren los intereses genuinos de los estudiantes.
⬝ Propician la construcción, profundización y conexión entre saberes. Involucran tareas desafiantes a resolver —pero no imposibles— y requieren de la integración de múltiples áreas del conocimiento para poder analizarlas y comprenderlas.
⬝ Desarrollan el pensamiento crítico y la creatividad. Requieren que los y las estudiantes busquen y analicen información, entiendan que hay muchas perspectivas para mirar una situación, hagan conexiones entre diferentes conceptos, propongan soluciones creativas, etcétera. ⬝ Facilitan el trabajo colaborativo y cooperativo entre pares y con otros y otras (docentes, familias, comunidad educativa, etcétera). Implican analizar y resolver diversas situaciones donde la variedad de perspectivas y experiencias enriquece el trabajo,
⬝ Promueven la gestión y monitoreo del propio aprendizaje. Al plantear preguntas desafiantes y complejas, los y las estudiantes deben ser innovadores e innovadoras en los modos de resolución, a la vez que reconocen qué y cómo aprenden.

La pregunta es un recurso invaluable en la Educación Steam Ampliada, lo que no implica que el o la docente sea siempre quien las elabora y propone. El proceso que se persigue al favorecer el desarrollo de capacidades fundamentales implica que los estudiantes se enfrenten a la necesidad no solo de buscar responder, sino, además, de aprender a preguntar.


Clic aquí (https://youtu.be/Chgn6qKQNTs?si=uqOxtx6dXNNRJapZ) para ver el video.

En el video, el Dr. David Perkins —Proyecto Zero en la Universidad de Harvard— reflexiona sobre lo siguiente: ¿Estamos enseñando conocimientos y potenciando habilidades verdaderamente útiles para nuestros estudiantes? (EduCaixaTV, 2019).

### 4.1.1. Ejemplos para el abordaje de preguntas

### | Ejemplo 1 |

En el curso han tenido momentos de diálogo y talleres en torno a las emociones y se reconoce un gran vínculo de los y las estudiantes con la música como forma de expresión. ¿Cómo diseñar una composición musical que exprese nuestras emociones? Esta pregunta centrada en el hacer puede vincular saberes de la Educación Artística y las Matemáticas en la Educación Secundaria y, por supuesto, con la educación emocional. Los y las estudiantes pueden indagar las relaciones entre la música y las emociones, analizar patrones rítmicos y crear composiciones musicales basadas en sus hallazgos.
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

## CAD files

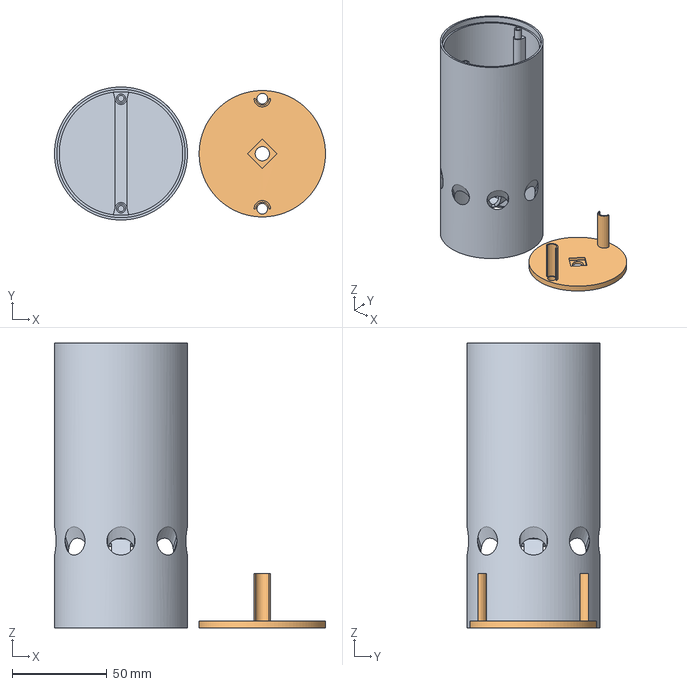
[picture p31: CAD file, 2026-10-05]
desafio/ETAPA 4 - Construcción y validación del CANSAT/cansat_3d/cansat_antir_1.0.3mf
142.6 x 70.0 x 150.0 mm
cansat_antir_1.0_BODY.stl
cansat_antir_1.0_LID.stl

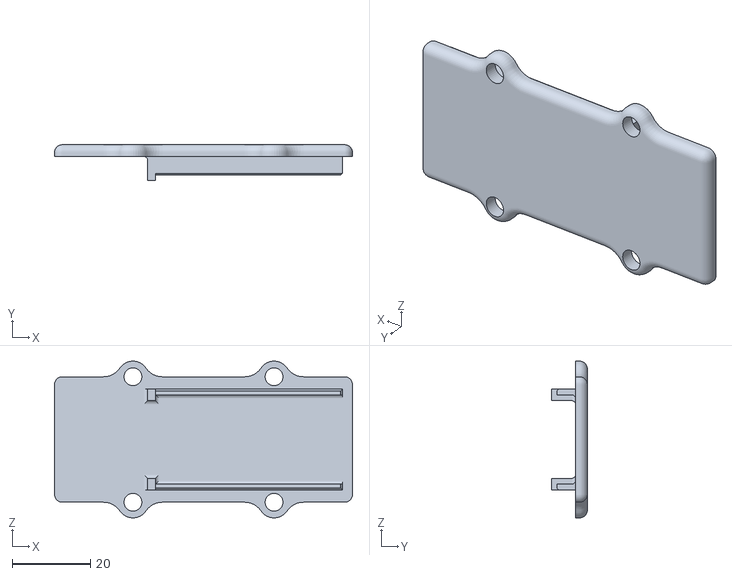
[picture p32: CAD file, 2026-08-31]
desafio/ETAPA 4 - Construcción y validación del CANSAT/Estación Terrena/Case/files/Meshtastic_heltec_v3_gehäuse_deckel_1.1.STL
76.0 x 9.10 x 40.0

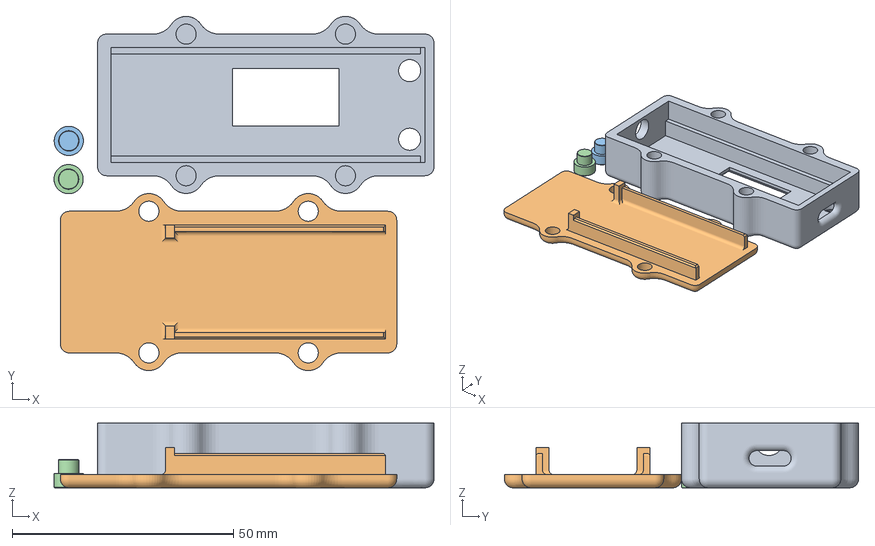
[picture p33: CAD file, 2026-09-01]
desafio/ETAPA 4 - Construcción y validación del CANSAT/Estación Terrena/Case/print/Meshtastic_heltec_v3_gehäuse_1.1.3mf
85.8 x 80.0 x 14.6 mm
Meshtastic_heltec_v3_gehäuse_1.1.STL
Meshtastic_heltec_v3_gehäuse_deckel_1.1.STL
Meshtastic_heltec_v3_taste_1.1.STL x 2

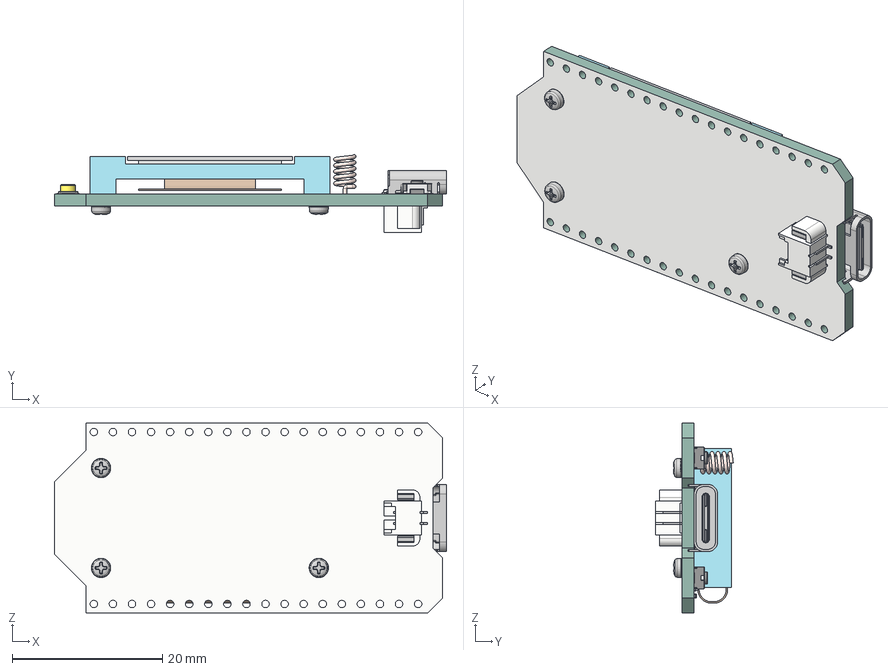
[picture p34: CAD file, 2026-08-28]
desafio/ETAPA 4 - Construcción y validación del CANSAT/Estación Terrena/Case/step/Heltec_V3.step
52.2 x 10.3 x 25.3 mm
board
screen_frame
90380A322_Phillips Rounded Head Thread-Forming Screws x 3
cover x 2
conn001 x 2
conn002 x 2
cap x 2
0402 Resistor x 2
0603 Chip SMD LED (1.6x0.8mm) x 2
IPEX U.FL-R-SMT
antenna
power socket
screen

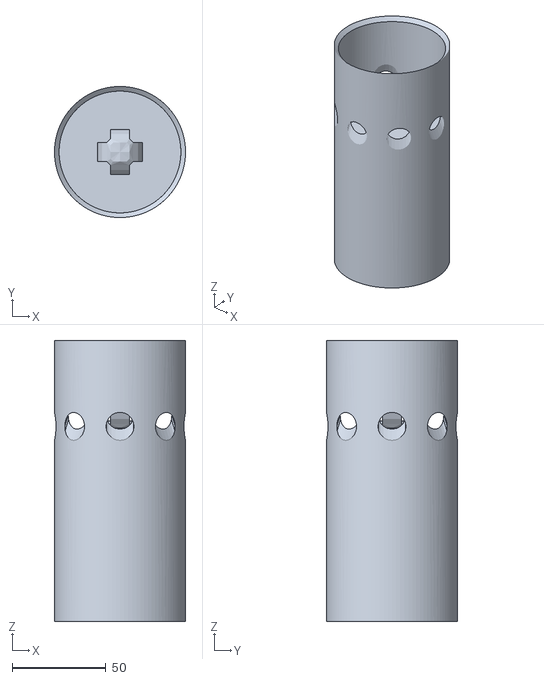
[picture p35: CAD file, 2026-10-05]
desafio/ETAPA 4 - Construcción y validación del CANSAT/cansat_3d/cansat_antir_1.0_BODY.stl
70.0 x 70.0 x 150.0

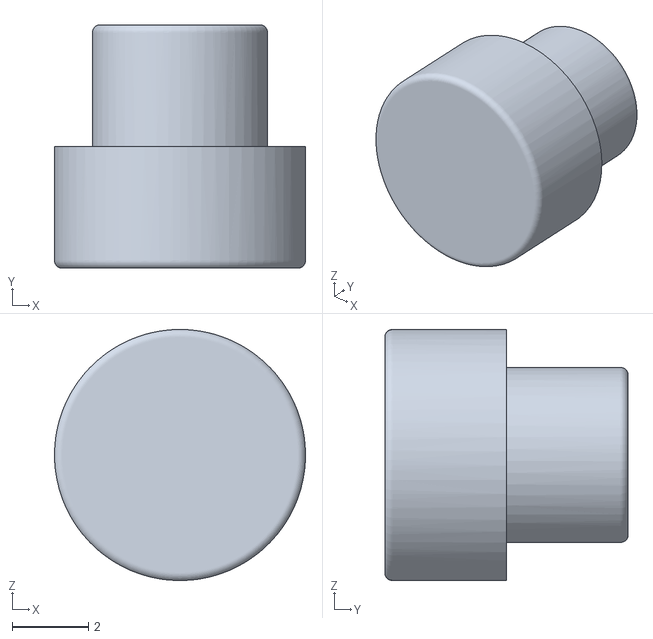
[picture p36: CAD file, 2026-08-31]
desafio/ETAPA 4 - Construcción y validación del CANSAT/Estación Terrena/Case/files/Meshtastic_heltec_v3_taste_1.1.STL
6.60 x 6.40 x 6.60

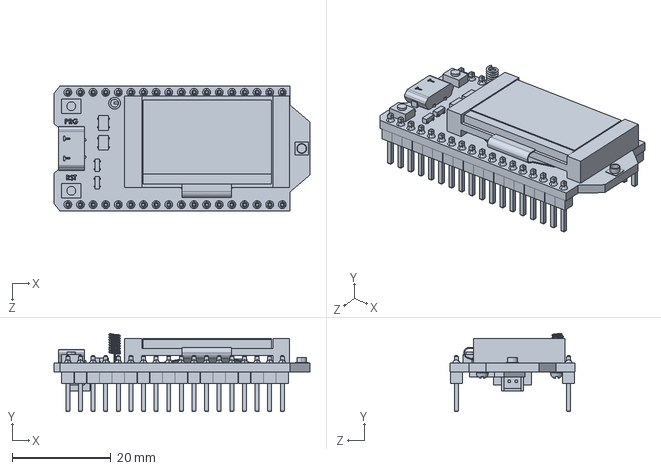
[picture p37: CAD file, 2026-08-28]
desafio/ETAPA 4 - Construcción y validación del CANSAT/Estación Terrena/Case/step/Heltec_ESP32_WIFI.Step
51.7 x 15.8 x 25.3 mm

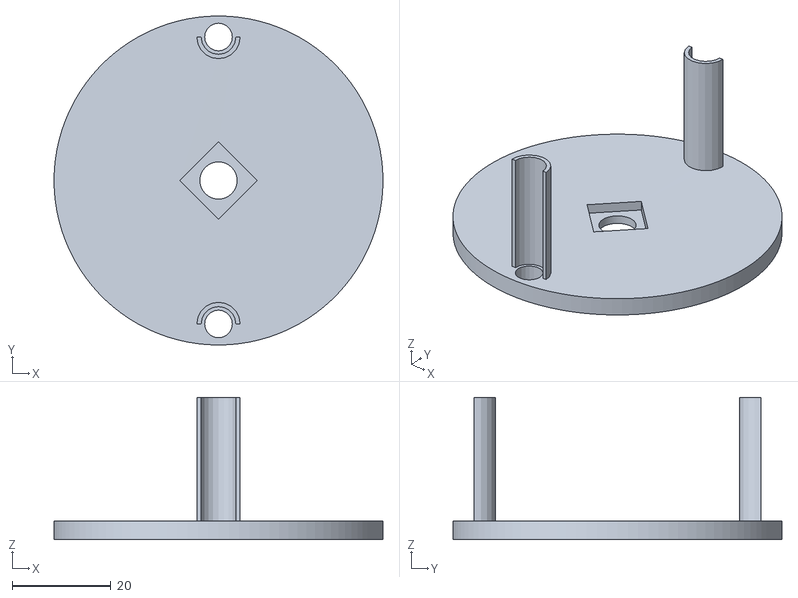
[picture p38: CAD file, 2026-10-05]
desafio/ETAPA 4 - Construcción y validación del CANSAT/cansat_3d/cansat_antir_1.0_LID.stl
66.5 x 66.5 x 28.8

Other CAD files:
desafio/ETAPA 4 - Construcción y validación del CANSAT/Estación Terrena/Case/files/Meshtastic_heltec_v3_gehäuse_1.1.STL
desafio/ETAPA 4 - Construcción y validación del CANSAT/cansat_3d/cansat_antir_1.0.blend

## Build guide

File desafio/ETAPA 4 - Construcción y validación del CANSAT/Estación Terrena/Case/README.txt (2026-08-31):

Case Heltec WiFi LoRa 32 (V3) , ESP32S3 + SX1262 LoRa Node Meshtastic by sebbo78 on Thingiverse: https://www.thingiverse.com/thing:7144975

Summary:
Case for Heltec LoRa Meshtestic

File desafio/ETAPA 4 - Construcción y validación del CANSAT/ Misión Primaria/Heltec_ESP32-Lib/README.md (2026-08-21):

# Heltec_ESP32 Library

English | [简体中文](#简体中文)

**Heltec ESP32 Library** contains extended examples: **LoRa/LoRaWAN related examples**, **factory test code**, **display related example code**, **Sensor example code**, **GPS example code**, etc.

The framework the library depends on, you can choose any of them:

- [Heltec ESP32 Frame Work 3.0.2](https://github.com/Heltec-Aaron-Lee/WiFi_Kit_series) 
- [espressif/arduino-esp32 at 3.0.2](https://github.com/espressif/arduino-esp32)

## CONTENT

1. [How to install this library](#how-to-install-this-library)
	- [Use Arduino Library Manager](#use-arduino-library-manager)
	- [Use Git](#use-git)
	
2. [How to use this library](#how-to-use-this-library)

3. [API Reference](#api-reference)

4. [Relevant Resources](#relevant-resources)

***

## How to install this library

*`We recommend using the Arduino library manager, it's the simplest way`*

### Use Arduino Library Manager

Open Arduino IDE, then Select `LIBRARY MANAGER`.

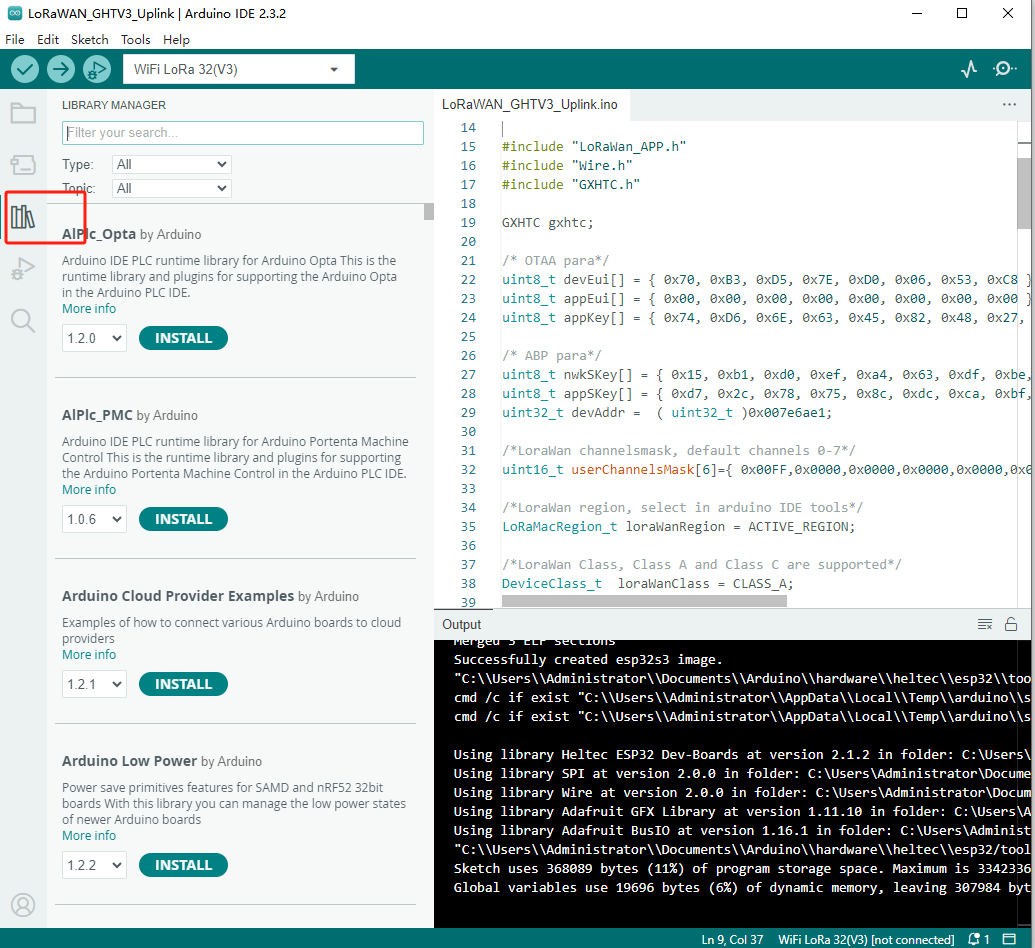
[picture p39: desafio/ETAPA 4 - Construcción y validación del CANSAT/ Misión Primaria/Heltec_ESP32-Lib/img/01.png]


Search `Heltec ESP32` and install it.

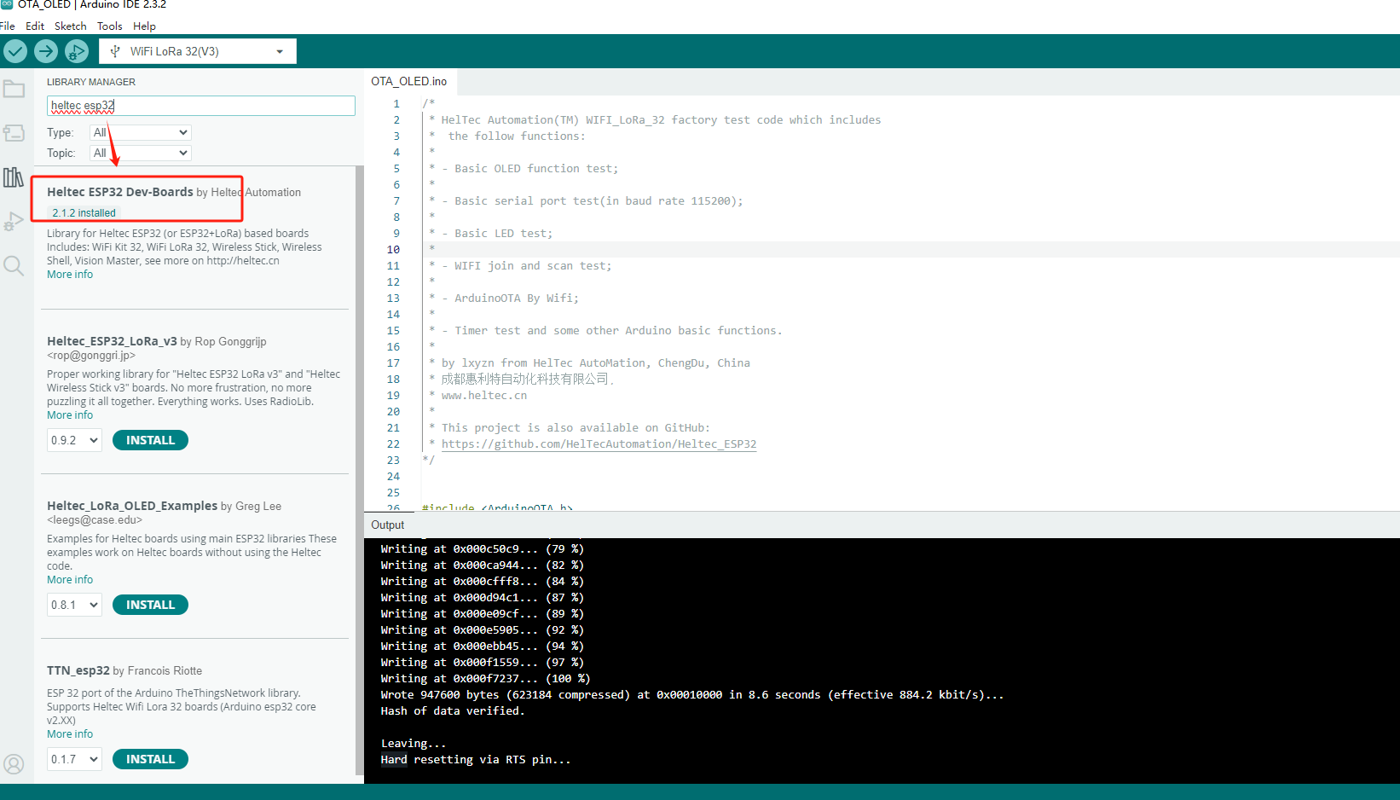
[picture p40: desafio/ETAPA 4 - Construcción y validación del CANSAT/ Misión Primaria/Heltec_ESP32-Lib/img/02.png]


### Use Git

*Firstly, make sure git and the Arduino IDE have been installed first. If not, please refer [How to install Git and Arduino IDE](https://docs.heltec.org/general/how_to_install_git_and_arduino.html). When Arduino is installed correctly, you will find a folder in "Username/Documents/Arduino/Library". **this library must in this path!***

Open "Git bash" in path `Username/Documents/Arduino/Library`, and input:

    git clone https://github.com/HelTecAutomation/Heltec_ESP32.git

You will see such a new folder in your library path, install done.



## How to use this library

A detailed step by step instructions to execute some examples available here:

[Heltec ESP32+LoRa Series Quick Start — esp32 latest documentation](https://docs.heltec.org/en/node/esp32/esp32_general_docs/quick_start.html#programming).

## API Reference

[OLED API](src/oled/API.md)

[LoRa API](src/lora/API.md)

## Relevant Resources

- [WiFi Kit 32](https://resource.heltec.cn/download/WiFi_Kit_32)

- [WiFi LoRa 32](https://resource.heltec.cn/download/WiFi_LoRa_32)

- [Wireless Stick](https://resource.heltec.cn/download/Wireless_Stick)

- [Wireless Stick Lite](https://resource.heltec.cn/download/Wireless_Stick_Lite)

- [Wireless Shell](https://resource.heltec.cn/download/Wireless_Shell)

- [WIFI Kit 32(v3)](https://resource.heltec.cn/download/WiFi_Kit_32_V3)

- [WIFI LoRa 32(v3)](https://resource.heltec.cn/download/WiFi_LoRa_32_V3)

- [Wireless Stick(v3)](https://resource.heltec.cn/download/Wireless_Stick_V3)

- [Wireless Stick Lite(v3)](https://resource.heltec.cn/download/Wireless_Stick_Lite_V3)

- [Wireless Paper](https://resource.heltec.cn/download/Wireless_Paper)

- [Wireless Tracker](https://resource.heltec.cn/download/Wireless_Tracker)

- [HT-CT62](https://resource.heltec.cn/download/HT-CT62)

- [Wireless Shell(v3)](https://resource.heltec.cn/download/Wireless_Shell_V3)

- [HT-DE01](https://resource.heltec.cn/download/HT-DE01)

If there is a "Limited" folder in the resources page, it means the product have limited resources that not public by default, refer to this document to download: [Get Limited Technical Resources](https://docs.heltec.org/general/view_limited_technical_data.html).

#### Note:
Please make sure use a high-quality Micro USB cable, it will reduce many problems.

[Summary of common problems](https://docs.heltec.org/en/node/esp32/esp32_general_docs/frequently_asked_questions.html)

&nbsp;

***
***
&nbsp;

## 简体中文

**这个Arduino库必须配合[Heltec ESP32编译环境](https://github.com/Heltec-Aaron-Lee/WiFi_Kit_series)或[espressif/arduino-esp32 at 3.0.2](https://github.com/espressif/arduino-esp32)一起使用！完整的“编译环境 + 库”的的教程可以参考这里：**[Heltec ESP32 Series Quick Start — esp32 latest documentation](https://docs.heltec.org/en/node/esp32/esp32_general_docs/quick_start.html#)

***

## 目录

1. [安装方法](#安装方法)
	- [通过Arduino库管理器安装](#通过Arduino库管理器安装)
	
	- [通过Git进行安装](#use-git)
	
2. [怎样使用这个库](#怎样使用这个库)

3. [API参考](#API参考)

4. [相关资源](#相关资源)

***

## 安装方法

*`强烈推荐使用Arduino自带的“库管理器”进行安装!`*

### 通过Arduino库管理器安装

打开Arduino IDE, 选择`项目`->`加载库`->`管理库...`，打开“库管理器”
搜索`Heltec ESP32`并安装.


&nbsp;



### 通过Git进行安装

*首先,请确保`Git`和`Arduino IDE`都已经正确安装。如果没有，请参考这里的安装方法[怎样安装Git和Arduino IDE](https://docs.heltec.org/general/how_to_install_git_and_arduino.html)。 *

**强调一下：这个库的路径必须位于操作系统的“文档/Arduino/libraries”文件夹内！！！文档文件夹是操作系统自带的，必须！必须！必须！**

在“文档/Arduino/libraries”路径下打开"Git bash"，输入:

    git clone https://github.com/HelTecAutomation/Heltec_ESP32.git

如果一切正常，应该是这样的

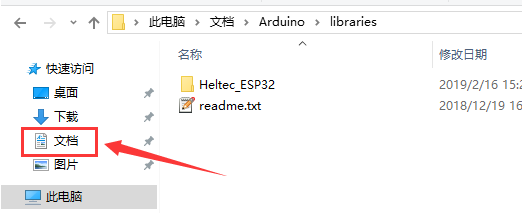
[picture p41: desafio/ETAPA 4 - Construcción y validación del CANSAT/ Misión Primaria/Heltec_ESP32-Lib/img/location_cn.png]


## 怎样使用这个库

如何运行一个例程？详细的使用指南：:

[Heltec ESP32+LoRa Series Quick Start — esp32 latest documentation](https://docs.heltec.org/en/node/esp32/esp32_general_docs/quick_start.html#programming)

## API参考
[OLED API](src/oled/API.md)

[LoRa API](src/lora/API.md)

## 相关资源

- [WiFi Kit 32](https://resource.heltec.cn/download/WiFi_Kit_32)
- [WiFi LoRa 32](https://resource.heltec.cn/download/WiFi_LoRa_32)
- [Wireless Stick](https://resource.heltec.cn/download/Wireless_Stick)
- [Wireless Stick Lite](https://resource.heltec.cn/download/Wireless_Stick_Lite)
- [Wireless Shell](https://resource.heltec.cn/download/Wireless_Shell)
- [WIFI Kit 32(v3)](https://resource.heltec.cn/download/WiFi_Kit_32_V3)
- [WIFI LoRa 32(v3)](https://resource.heltec.cn/download/WiFi_LoRa_32_V3)
- [Wireless Stick(v3)](https://resource.heltec.cn/download/Wireless_Stick_V3)
- [Wireless Stick Lite(v3)](https://resource.heltec.cn/download/Wireless_Stick_Lite_V3)
- [Wireless Paper](https://resource.heltec.cn/download/Wireless_Paper)
- [Wireless Tracker](https://resource.heltec.cn/download/Wireless_Tracker)
- [Ct62](https://resource.heltec.cn/download/Ct62)
- [Wireless Shell(v3)](https://resource.heltec.cn/download/Wireless_Shell_V3)
- [HT-DE01](https://resource.heltec.cn/download/HT-DE01)

如果在资源下载页中看到了`Limited`文件夹，表面这个产品有非公开的技术资料。[获取受限资源的方法](https://docs.heltec.org/general/view_limited_technical_data.html)

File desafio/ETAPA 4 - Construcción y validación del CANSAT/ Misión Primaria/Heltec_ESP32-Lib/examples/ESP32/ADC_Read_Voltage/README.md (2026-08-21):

# ADC_Read_Voltage_Simple
Basic ADC example read voltage.

# ADC_Read_Voltage_Accurate
A function that improves the defaulot ADC reading accuracy to within 1%

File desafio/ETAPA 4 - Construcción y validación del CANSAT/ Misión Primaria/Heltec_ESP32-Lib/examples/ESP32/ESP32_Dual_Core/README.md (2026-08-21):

## Contents

- [The Overview](#the-overview)
- [ShowCore](#showcore)
- [MoveCore](#movecore)
- [SpeedTest](#speedtest)
- [Information](#information)

# The Overview

- The ESP32 chip has three cores.
- Two cores are fast cores and one core is a low-power core.
- Which is an example of ESP32 Dual Core on Arduino IDE including Data Passing and Task Synchronization.

## ShowCore

In the first step, we need to know which core the current program is running on.
We need a code to print the current core from the serial port.

```
Serial.println(xPortGetCoreID());
```



We prepared an [example](https://github.com/Heltec-Aaron-Lee/WiFi_Kit_series/tree/master/esp32/libraries/ESP32/examples/ESP32_Dual_Core/examples/Showcore) for you.

## MoveCore

Run the program with the specified core.


- We use the following code to perform core switching
```
   xTaskCreatePinnedToCore(
    codeForTask1,           /*Task Function. */
    "Task_1",               /*name of task. */
    1000,                   /*Stack size of task. */
    NULL,                   /* parameter of the task. */
    1,                      /* proiority of the task. */
    &Task1,                 /* Task handel to keep tra ck of created task. */
    0);                     /* choose Core */
```

Check this [example](https://github.com/Heltec-Aaron-Lee/WiFi_Kit_series/tree/master/esp32/libraries/ESP32/examples/ESP32_Dual_Core/examples/Movecore) to see how you can switch the core.

## SpeedTest

Test the speed of the two cores under different conditions.


In this [example](https://github.com/Heltec-Aaron-Lee/WiFi_Kit_series/tree/master/esp32/libraries/ESP32/examples/ESP32_Dual_Core/examples/SpeedTest) the program is running as follows:



The result of the operation is as follows:

At this time, 0 core and 1 core full speed synchronous processing independent tasks.

## Information



- [PinoutDiagram](https://github.com/Heltec-Aaron-Lee/WiFi_Kit_series/blob/master/PinoutDiagram/WIFI%20LoRa%2032(V2)%20.pdf)
- node: [WIFI LoRa 32 V2](https://item.taobao.com/item.htm?spm=a1z10.1-c.w4004-17008247508.4.7bdf1d6f2XG3ID&id=575190433694) 
- Arduino 18.04

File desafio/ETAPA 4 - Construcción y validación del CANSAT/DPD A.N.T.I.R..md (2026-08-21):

# Planteo de diseño del equipo A.N.T.I.R.

## Misión primaria

Además de cumplir con la medición obligatoria de presión y temperatura decidieron ampliar considerablemente la telemetría incorporando:

* BMP280 (presión y temperatura)
* MPU6050 (aceleración y velocidad angular)
* GPS NEO-8M (latitud, longitud y altitud)

Todos esos datos serán almacenados en MicroSD y transmitidos en tiempo real mediante LoRa SX1278.

## Misión secundaria

Consiste en utilizar una **ESP32-CAM** apuntando hacia el suelo para fotografiar la costa de Mar del Plata durante el descenso. El objetivo no es solamente obtener imágenes sino realizar un registro ambiental orientado a:

* detectar residuos en playas;
* documentar la evolución de la contaminación;
* generar evidencia útil para futuras políticas ambientales;
* colaborar eventualmente con organizaciones locales. 

## Arquitectura electrónica

Eligieron como computadora principal un ESP32 DevKit con los siguientes pPeriféricos:

* BMP280
* MPU6050
* GPS NEO-8M
* ESP32-CAM
* LoRa SX1278
* MicroSD
* batería LiPo 3,7 V
* regulador MP1584. 

## Estructura

Plantean:

* carcasa impresa en 3D (PETG),
* protección mediante goma EVA,
* paracaídas superior,
* componentes montados internamente. 

## Presupuesto de masa

Estimaron **211 gramos**, por lo que quedarían aproximadamente **39 gramos por debajo del límite reglamentario de 250 g**, dejando un margen razonable. 

## Operación prevista

El funcionamiento propuesto es:

1. Leer sensores.
2. Obtener posición GPS.
3. Capturar fotografías.
4. Guardar todo en MicroSD.
5. Transmitir telemetría por LoRa en tiempo real. 

## Plan de pruebas

Prevén validar individualmente:

* sensores;
* cámara;
* GPS;
* LoRa;
* batería;
* regulador;
* paracaídas.

Luego realizarán:

* integración completa;
* prueba de caída;
* prueba de vibraciones;
* verificación de dimensiones;
* simulación de vuelo con telemetría.

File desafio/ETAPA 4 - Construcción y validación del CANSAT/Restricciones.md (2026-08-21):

# Restricciones técnicas

Las restricciones técnicas más importantes que condicionan el diseño son:

- **Misión primaria:** el CanSat debe realizar durante el descenso un *sondeo atmosférico midiendo presión y temperatura*.

- **Dimensiones del CanSat:** el contenedor debe cumplir estrictamente:
	* Forma cilíndrica.
	* **70 mm de diámetro.**
	* **150 mm de longitud total (sin contar el paracaídas).** 

- **Peso máximo:** **250 gramos máximo**, incluyendo toda la carga útil. 

- **Sistema de descenso:** debe disponer de un sistema de descenso blando, normalmente un paracaídas. 

- **Alimentación:** debe utilizar baterías o pilas comerciales aprobadas para uso comercial. 

- **Electrónica:** puede utilizar la electrónica provista por CONAE de manera opcional. Para la misión secundaria debe ser compatible con dicha electrónica. 

- **Geometría exterior:** no puede haber:
	* antenas rígidas,
	* tornillos sobresalientes,
	* sensores,
	* soportes,
	* ni ninguna otra protuberancia que sobresalga del cilindro. 

- **Materiales permitidos:** se pueden utilizar materiales reciclables para el contenedor. No se aceptan materiales:
	* tóxicos,
	* contaminantes. 

- **Misión secundaria: ** la misión secundaria es opcional pero puntúa favorablemente. Para esta edición el objetivo propuesto es *capturar imágenes o video durante la liberación, apogeo y/o descenso.* 

- **Prohibiciones:** no se aceptan:
	* explosivos,
	* productos químicos peligrosos,
	* mecanismos que puedan afectar el despliegue,
	* mecanismos que comprometan la estabilidad del cohete,
	* experimentos con animales. 

- **Validación:** durante el desarrollo deberán demostrar mediante pruebas que el diseño es viable y cumple dimensiones, peso e integración antes de ser seleccionados para el lanzamiento.

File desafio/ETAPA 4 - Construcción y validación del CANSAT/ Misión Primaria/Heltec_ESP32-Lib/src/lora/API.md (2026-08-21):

# Heltec LoRa basic library API

## Include Library

```arduino
#include <LoRa.h>
```

## Setup

### Begin

Initialize the library with the specified frequency.

```arduino
LoRa.begin(frequency);
```
 * `frequency` - frequency in Hz (`433E6`, `866E6`, `915E6`)

Returns `1` on success, `0` on failure.

### Set pins

Override the default `NSS`, `NRESET`, and `DIO0` pins used by the library. **Must** be called before `LoRa.begin()`.

```arduino
LoRa.setPins(ss, reset, dio0);
```
 * `ss` - new slave select pin to use, defaults to `18`
 * `reset` - new reset pin to use, defaults to `14`
 * `dio0` - new DIO0 pin to use, defaults to `26`

This call is optional and only needs to be used if you need to change the default pins used.

### Set SPI Frequency

Override the default SPI frequency of 10 MHz used by the library. **Must** be called before `LoRa.begin()`.

```arduino
LoRa.setSPIFrequency(frequency);
```
 * `frequency` - new SPI frequency to use, defaults to `10E6`

This call is optional and only needs to be used if you need to change the default SPI frequency used. Some logic level converters cannot support high speeds such as 10 MHz, so a lower SPI frequency can be selected with `LoRa.setSPIFrequency(frequency)`.

### End

Stop the library

```arduino
LoRa.end()
```

## Sending data

### Begin packet

Start the sequence of sending a packet.

```arduino
LoRa.beginPacket();

LoRa.beginPacket(implicitHeader);
```

 * `implicitHeader` - (optional) `true` enables implicit header mode, `false` enables explicit header mode (default)

Returns `1` on success, `0` on failure.

### Writing

Write data to the packet. Each packet can contain up to 255 bytes.

```arduino
LoRa.write(byte);

LoRa.write(buffer, length);
```
* `byte` - single byte to write to packet

or

* `buffer` - data to write to packet
* `length` - size of data to write

Returns the number of bytes written.

**Note:** Other Arduino `Print` API's can also be used to write data into the packet

### End packet

End the sequence of sending a packet.

```arduino
LoRa.endPacket()
```

Returns `1` on success, `0` on failure.

## Receiving data

### Parsing packet

Check if a packet has been received.

```arduino
int packetSize = LoRa.parsePacket();

int packetSize = LoRa.parsePacket(size);
```

 * `size` - (optional) if `> 0` implicit header mode is enabled with the expected a packet of `size` bytes, default mode is explicit header mode

Returns the packet size in bytes or `0` if no packet was received.

### Continuous receive mode

#### Register callback

Register a callback function for when a packet is received.

```arduino
LoRa.onReceive(onReceive);

void onReceive(int packetSize) {
 // ...
}
```

 * `onReceive` - function to call when a packet is received.

#### Receive mode

Puts the radio in continuous receive mode.

```arduino
LoRa.receive();

LoRa.receive(int size);
```

 * `size` - (optional) if `> 0` implicit header mode is enabled with the expected a packet of `size` bytes, default mode is explicit header mode

The `onReceive` callback will be called when a packet is received.

### Packet RSSI

```arduino
int rssi = LoRa.packetRssi();
```

Returns the RSSI of the received packet.

### Packet SNR

```arduino
float snr = LoRa.packetSnr();
```

Returns the estimated SNR of the received packet in dB.

### Available

```arduino
int availableBytes = LoRa.available()
```

Returns number of bytes available for reading.

### Peeking

Peek at the next byte in the packet.

```arduino
byte b = LoRa.peek();
```

Returns the next byte in the packet or `-1` if no bytes are available.

### Reading

Read the next byte from the packet.

```arduino
byte b = LoRa.read();
```

Returns the next byte in the packet or `-1` if no bytes are available.

**Note:** Other Arduino [`Stream` API's](https://www.arduino.cc/en/Reference/Stream) can also be used to read data from the packet

## Other radio modes

### Idle mode

Put the radio in idle (standby) mode.

```arduino
LoRa.idle();
```

### Sleep mode

Put the radio in sleep mode.

```arduino
LoRa.sleep();
```

## Radio parameters

### TX Power

Change the TX power of the radio.

```arduino
LoRa.setTxPower(txPower);

LoRa.setTxPower(txPower, outputPin);
```
 * `txPower` - TX power in dB, defaults to `14`
 * `outputPin` - (optional) PA output pin, supported values are `PA_OUTPUT_RFO_PIN` and `PA_OUTPUT_PA_BOOST_PIN`, defaults to `PA_OUTPUT_PA_BOOST_PIN`.

Supported values are between `2` and `17` for `PA_OUTPUT_PA_BOOST_PIN`, `0` and `14` for `PA_OUTPUT_RFO_PIN`.

Most modules have the PA output pin connected to PA BOOST,

### Frequency

Change the frequency of the radio.

```arduino
LoRa.setFrequency(frequency);
```
 * `frequency` - frequency in Hz (`433E6`, `866E6`, `915E6`)

### Spreading Factor

Change the spreading factor of the radio.

```arduino
LoRa.setSpreadingFactor(spreadingFactor);
```
 * `spreadingFactor` - spreading factor, defaults to `11`

Supported values are between `6` and `12`. If a spreading factor of `6` is set, implicit header mode must be used to transmit and receive packets.

### Signal Bandwidth

Change the signal bandwidth of the radio.

```arduino
LoRa.setSignalBandwidth(signalBandwidth);
```

 * `signalBandwidth` - signal bandwidth in Hz, defaults to `125E3`.

Supported values are `7.8E3`, `10.4E3`, `15.6E3`, `20.8E3`, `31.25E3`, `41.7E3`, `62.5E3`, `125E3`, and `250E3`.

### Coding Rate

Change the coding rate of the radio.

```arduino
LoRa.setCodingRate4(codingRateDenominator);
```

 * `codingRateDenominator` - denominator of the coding rate, defaults to `5`

Supported values are between `5` and `8`, these correspond to coding rates of `4/5` and `4/8`. The coding rate numerator is fixed at `4`.

### Preamble Length

Change the preamble length of the radio.

```arduino
LoRa.setPreambleLength(preambleLength);
```

 * `preambleLength` - preamble length in symbols, defaults to `8`

Supported values are between `6` and `65535`.

### Sync Word

Change the sync word of the radio.

```arduino
LoRa.setSyncWord(syncWord);
```

 * `syncWord` - byte value to use as the sync word, defaults to `0x34`

### CRC

Enable or disable CRC usage, by default a CRC is not used.

```arduino
LoRa.enableCrc();

LoRa.disableCrc();
```

### iqInverted

Enable or disable iqInverted for TX/RX

```arduino
LoRa.disableInvertIQ();
LoRa.enableInvertIQ();
LoRa.enableTxInvertIQ();
LoRa.enableRxInvertIQ();

```

## Other functions

### Random

Generate a random byte, based on the Wideband RSSI measurement.

```
byte b = LoRa.random();
```

Returns random byte.

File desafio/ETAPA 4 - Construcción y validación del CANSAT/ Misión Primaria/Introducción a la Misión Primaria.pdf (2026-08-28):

Introducción a la Misión Primaria

Listado de

materiales e instrucciones

(22026 Asociación de Cohetería Experimental y Modelista de Argentina para la | |
COMISION NACIONAL DE ACTIVIDADES ESPACIALES | CONAE

La Agencia Espacial Argentina

¡FELICITACIONES! | E
La propuesta de tu equipo fue vista con mucho interés por nuestro | 1 los $ | El
equipo y este kit les dará la oportunidad de pasar la siguiente etapa. Los materiales incluidos servirán de soporte para cumplir la misión | 00000000 > | .

primaria y los ayudarán a completar la misión secundaria que se han
propuesto. LISTADO DE MATERIALES | 3 | 3 ESP32-LORA (2 unidades) y Sensor: Presión BMP280 (1 unidad) | El
Y Protoboard 830 Puntos Arduino Pic Avr (1 unidad) | | | A Al y Cables Dupont Macho Macho | | | 213)
Y Cable Dupont Macho Hembra | A Y Cable Dupont Hembra Hembra | dl
y Cable Micro Usb Carga Rapida (1 unidad) | | | A | Ar Y Manual (1 unidad) | + 511
Y Miscelánea CANSAT y sponsors (10 unidades)
LEER CON ATENCIÓN | > Debido a la gran variedad de configuraciones y sistemas operativos | e | » ¿Te de cada destinatario de este kit, se ofrece a continuación una
posible configuración. De ninguna forma este manual agota las | | | El posibilidades. Estamos para recibir sus consultas específicas. | | PLACA DE DESARROLLO HELTEC ESP32+LoRa | | | Pas
Microprocesador: ESP32 (dual-core 32- | |
bit MCU + ULP core), con chip LoRa
SX1276/5X1278, programable por Micro | | a | 3 USB con regulador de voltaje, integrado | , E | | | 2 con WiFi, LoRa y Bluetooth y pantalla | | | E
OLED de 0.96 pulgadas de 128*64, | | | * Puerto CP2102 USB to serial. | | Información adicional en: | | | S | | $ 2 | $

=

INSTALACION de IDE y DRIVERS
https://github.com/Heltec-Aaron- Para poder programar los ESP32, se utiliza el Arduino IDE el cual esta | Lee/WiFi | heltec esp32 ind disponible para todos los sistemas operativos. El mismo se descarga | ex.json desde el siguiente link (https://www arduino.cc/en/software).
Luego, en el menú de HERRAMIENTAS, seleccionar la placa "Buscamos la palabra Heltec ESP32 y una vez encontrado el paquete Heltec ESP32 Arduino IDE 1.8.19 | series Dev-Boards

O Boards Manager
The open-source Arduino Software (IDE) makes it easy to write code | Windows app wn 8.1 | | Get
and upload It to the board. This software can be used with any | Linux 32 Arduino board. | Linux 64 ts
32, | 32, WIFI | Lt,
Active development of the Arduino software is hosted by GitHub. | Notes. | + | 3 See the instructions for building the code. Latest release source code archives are | here. The archives are PGP-signed so they can be verified using this gpg key. | |

Para poder disponer de todas las placas de la firma HELTEC, sobre todo la que vamos a utilizar nosotros es necesario instalar una librería. Esta
OS | 9 | librería nos permitirá que el IDE nos reconozca inmediatamente y sin mayores inconvenientes el dispositivo a configurar.
Ñ | Por último, debemos instalar las librerias de Heltec ESP32, LoRa y 4 | SFE_BMP180 o cualquier otra necesaria para los sensores a conectar en
e | el menú de HERRAMIENTAS >> ADMINISTRAR BIBLIOTECAS: | E de ona:
(12 | [00 Teno por | |
sl | mientras: Complacón | Type Al | ropic an | =
O | después de abr | O | editor externo. cdo Oe | =l | o | +
po | e | Hats Lor
(atar ao cundo edo | está ora)
| A partir de aquí, lo único que hay que hacer es comenzar a programar!

En la casilla de gestor de URLs agregar:

Código fuente Transmisor (TX) y Receptor (RX) | Validación en Monitor Serial del IDE
El código fuente a cargar tanto para el transmisor como para el receptor, | Una vez realizada la carga de ambos sketch, tanto para RX como TX, se encuentra en el repositorio público detallado a continuación: | vamos a validar ambos entornos
https://gitlab.com/lu4ba.mat/PrototipoCansat2026 | Primero energizamos el Transmisor (TX) y nos conectamos al USB de la
placa. Luego de eso abrimos el Serial Monitor (dentro del menú Tools), y NOTA: Son EJEMPLOS didácticos, pueden modificarse para adaptarse a | presionamos el botón de reset de la placa Heltec Lora ESP32 para que
la misión requerida | inicie nuevamente. En la pantalla del Serial Monitor, debieran aparecer
los mensajes (en nuestro caso lo cambiamos en código al español, por lo
cual no se va a ver exactamente ¡gual). AA | Para el caso del receptor es el mismo procedimiento pero con la otra placa Heltec Lora ESP32. Al resetearlo veremos los mensajes si esta E | . | todo OK a nivel de recepción. También se verán los mensajes en español, como mencionamos anteriormente . | >
fo | Hardware - Diagrama de conexionado
En esta nueva versión de hardware que se estará utilizando para la ES | E | E | E | edición integrado 2026, con contamos el módulo no LORA, solo la con antena el módulo correspondiente, ESP32, sino una que pantalla viene E A | del tipo OLED, y un conector para alimentación externa. Esto simplifica considerablemente el armado del prototipo, con la misión 4. | e | primaria ya incluida en el sketch (código) provisto. TX

El conexionado entre el módulo BMP180 y el ESP32, requiere solo de 4

cables:

Heltec LORA ESP32 (V2
Fa 1
| a . | En el caso de BMP 280, usamos solo SCL y SDA.
q | 1: | Agradecemos a Matías Graiño por el asesoramiento y la confección
Y | del material educativo que forma parte de este manual. as RX

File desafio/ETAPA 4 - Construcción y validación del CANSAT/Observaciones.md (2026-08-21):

# Información importante aportada por CONAE

## Problemas con la antena

Hemos verificado una alerta de los fabricantes de la placa de desarrollo que advierten que **NO SE DEBE ENERGIZAR SIN CONECTAR LA ANTENA.** Tanto por puerto USB o batería, y aunque no se envíe ningún comando por radio, **NO SE PUEDE ENCHUFAR SIN ANTES CONECTAR LA ANTENA.** Se corre el riesgo de quemar la etapa de TX/RX.

## Variante de la placa de desarrollo

Debido a que recibimos y distribuimos en el Kit las **PLACAS DE DESARROLLO en la versión 3.2**, las referencias del manual no son las que corresponden, ya que nos informan que el PIN OUT es diferente. Estamos trabajando en los códigos para solucionar el problema.

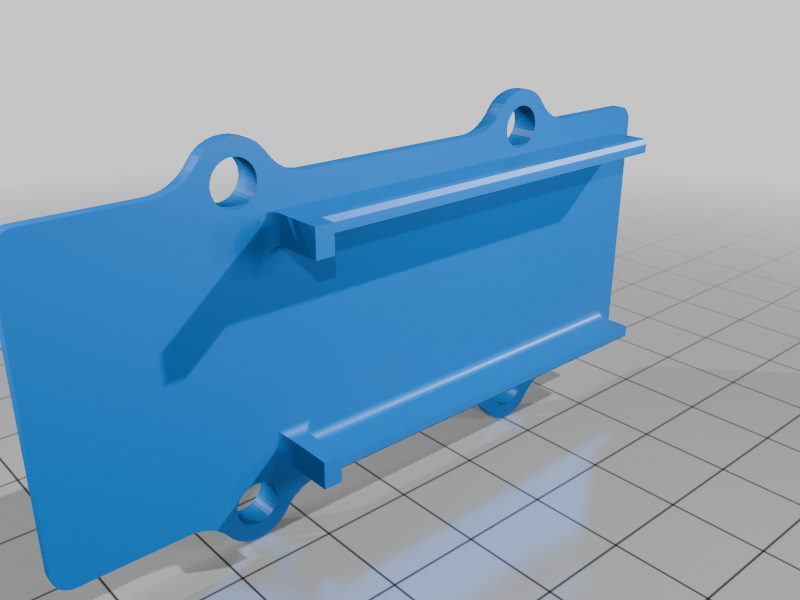
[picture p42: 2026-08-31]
desafio/ETAPA 4 - Construcción y validación del CANSAT/Estación Terrena/Case/images/Meshtastic_heltec_v3_gehäuse_deckel_1.1.png

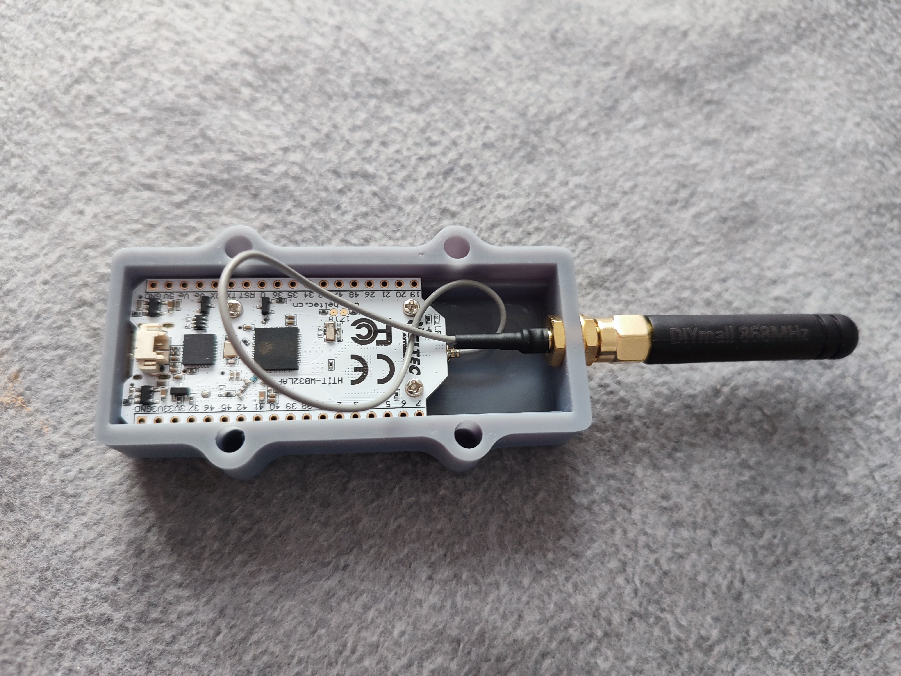
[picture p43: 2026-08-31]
desafio/ETAPA 4 - Construcción y validación del CANSAT/Estación Terrena/Case/images/IMG_20250914_142141.jpg

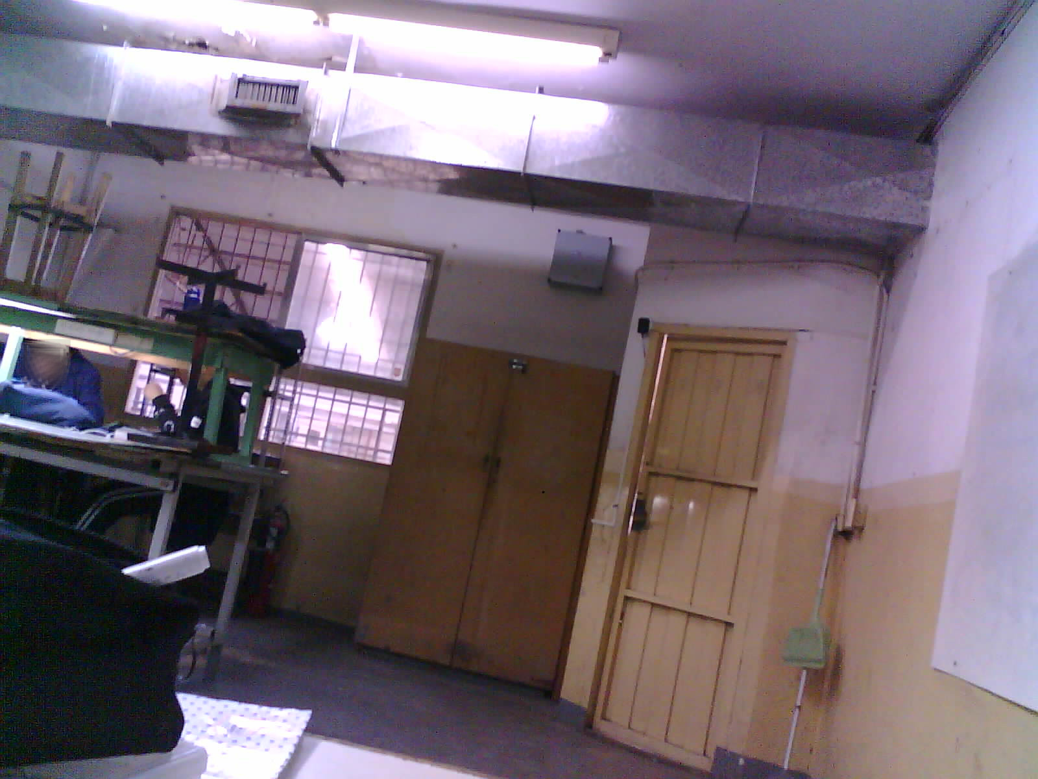
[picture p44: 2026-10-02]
desafio/ETAPA 4 - Construcción y validación del CANSAT/cam/photos/foto_00007.jpg

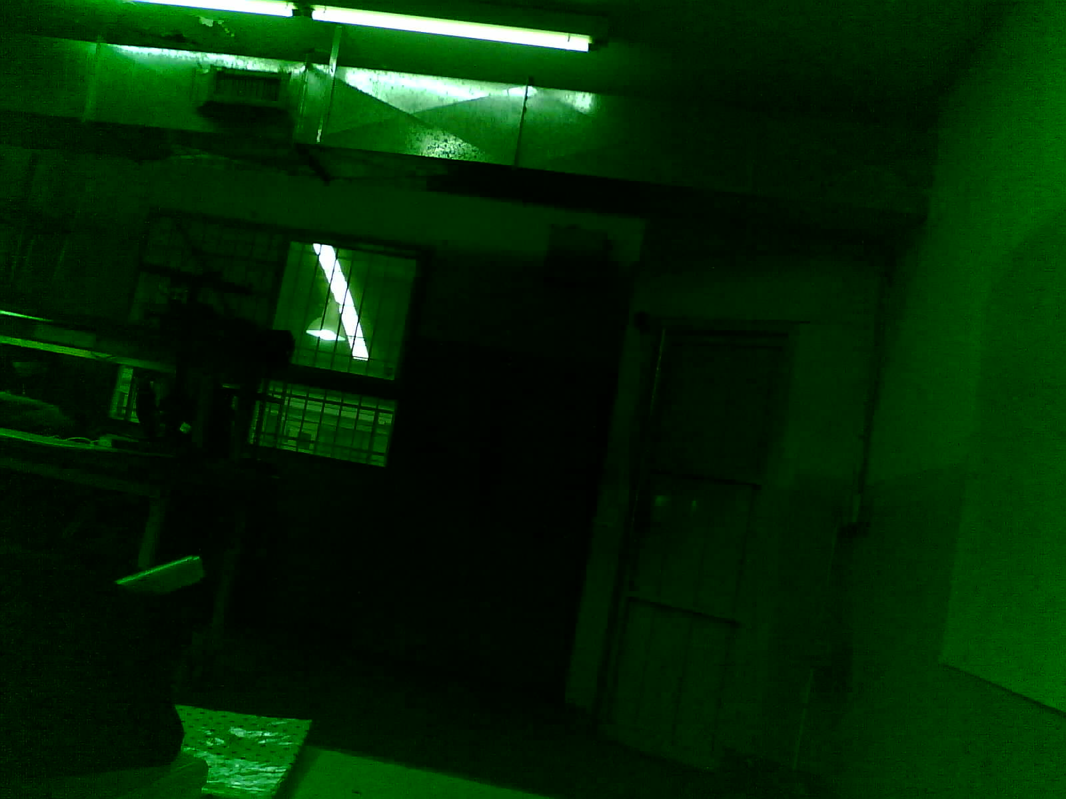
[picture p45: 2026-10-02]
desafio/ETAPA 4 - Construcción y validación del CANSAT/cam/photos/foto_00005.jpg

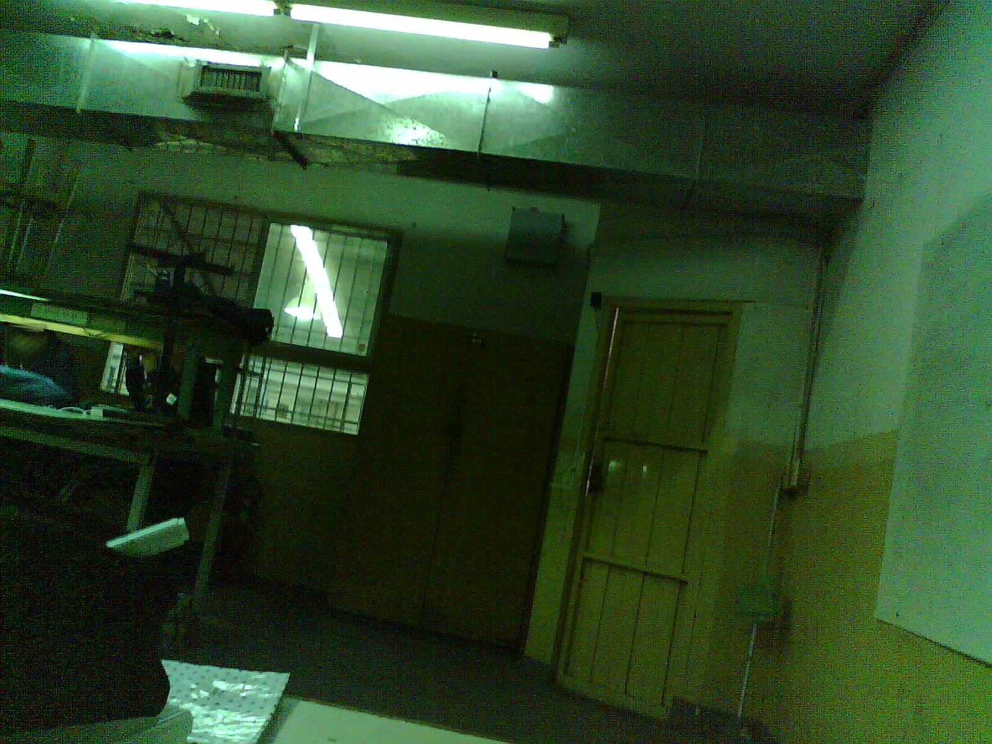
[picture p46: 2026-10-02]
desafio/ETAPA 4 - Construcción y validación del CANSAT/cam/photos/foto_00006.jpg

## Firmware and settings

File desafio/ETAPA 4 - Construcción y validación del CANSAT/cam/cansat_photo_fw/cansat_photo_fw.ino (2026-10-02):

/*  Firmware ES32-CAM A.N.T.I.R.
    E.E.S.T. N.°5 "Amancio Williams"
    Septiembre de 2026

    Toma fotos cada 5 segundos si hay un estado LOW en el GPIO12
    
    ESP32-CAM AI-Thinker Pinout Guide: GPIOs Usage Explained
    https://randomnerdtutorials.com/esp32-cam-ai-thinker-pinout/
*/

#include "esp_camera.h"
#include "FS.h"
#include "SD_MMC.h"

// ESP32-CAM AI-Thinker
#define PWDN_GPIO_NUM 32
#define RESET_GPIO_NUM -1
#define XCLK_GPIO_NUM 0
#define SIOD_GPIO_NUM 26
#define SIOC_GPIO_NUM 27

#define Y9_GPIO_NUM 35
#define Y8_GPIO_NUM 34
#define Y7_GPIO_NUM 39
#define Y6_GPIO_NUM 36
#define Y5_GPIO_NUM 21
#define Y4_GPIO_NUM 19
#define Y3_GPIO_NUM 18
#define Y2_GPIO_NUM 5
#define VSYNC_GPIO_NUM 25
#define HREF_GPIO_NUM 23
#define PCLK_GPIO_NUM 22

// GPIO que habilita las fotos
#define TRIGGER_GPIO 12

unsigned long ultimaFoto = 0;
unsigned long numeroFoto = 0;

void setup() {
  Serial.begin(115200);
  delay(1000);

  pinMode(TRIGGER_GPIO, INPUT_PULLUP);

  // Configuración de cámara
  camera_config_t config;

  config.ledc_channel = LEDC_CHANNEL_0;
  config.ledc_timer = LEDC_TIMER_0;

  config.pin_d0 = Y2_GPIO_NUM;
  config.pin_d1 = Y3_GPIO_NUM;
  config.pin_d2 = Y4_GPIO_NUM;
  config.pin_d3 = Y5_GPIO_NUM;
  config.pin_d4 = Y6_GPIO_NUM;
  config.pin_d5 = Y7_GPIO_NUM;
  config.pin_d6 = Y8_GPIO_NUM;
  config.pin_d7 = Y9_GPIO_NUM;

  config.pin_xclk = XCLK_GPIO_NUM;
  config.pin_pclk = PCLK_GPIO_NUM;
  config.pin_vsync = VSYNC_GPIO_NUM;
  config.pin_href = HREF_GPIO_NUM;

  config.pin_sccb_sda = SIOD_GPIO_NUM;
  config.pin_sccb_scl = SIOC_GPIO_NUM;

  config.pin_pwdn = PWDN_GPIO_NUM;
  config.pin_reset = RESET_GPIO_NUM;

  config.xclk_freq_hz = 20000000;
  config.pixel_format = PIXFORMAT_JPEG;

  if (psramFound()) {
    config.frame_size = FRAMESIZE_UXGA;
    config.jpeg_quality = 10;
    config.fb_count = 2;
  } else {
    config.frame_size = FRAMESIZE_SVGA;
    config.jpeg_quality = 12;
    config.fb_count = 1;
  }

  // Inicializar cámara
  esp_err_t err = esp_camera_init(&config);

  if (err != ESP_OK) {
    Serial.printf("Error cámara: 0x%x\n", err);
    return;
  }

  // Inicializar SD
  if (!SD_MMC.begin("/sdcard", true)) {
    Serial.println("Error inicializando SD");
    return;
  }

  uint8_t cardType = SD_MMC.cardType();

  if (cardType == CARD_NONE) {
    Serial.println("No hay tarjeta SD");
    return;
  }

  Serial.println("Cámara y SD inicializadas.");

  // Buscar el último número de foto existente en la SD para no sobrescribir
  numeroFoto = obtenerUltimoNumeroFoto();
  Serial.printf("Próxima foto será: foto_%05lu.jpg\n", numeroFoto + 1);
}

void loop() {

  // GPIO en LOW = tomar fotos
  if (digitalRead(TRIGGER_GPIO) == LOW) {

    if (millis() - ultimaFoto >= 5000) {
      ultimaFoto = millis();
      tomarFoto();
    }

  }
  delay(10);
}

void tomarFoto() {

  camera_fb_t *fb = esp_camera_fb_get();

  if (!fb) {
    Serial.println("Error capturando imagen");
    return;
  }

  numeroFoto++;

  char nombreArchivo[32];
  sprintf(nombreArchivo, "/foto_%05lu.jpg", numeroFoto);

  Serial.print("Guardando: ");
  Serial.println(nombreArchivo);

  File archivo = SD_MMC.open(nombreArchivo, FILE_WRITE);

  if (!archivo) {
    Serial.println("No se pudo abrir el archivo");
    esp_camera_fb_return(fb);
    return;
  }

  archivo.write(fb->buf, fb->len);
  archivo.close();

  Serial.printf("Foto guardada (%u bytes)\n", fb->len);

  esp_camera_fb_return(fb);
}

// Función auxiliar para leer la SD y encontrar el número más alto guardado
unsigned long obtenerUltimoNumeroFoto() {
  File root = SD_MMC.open("/");
  if (!root) {
    return 0;
  }
  if (!root.isDirectory()) {
    return 0;
  }

  unsigned long maxNum = 0;
  File file = root.openNextFile();
  while (file) {
    if (!file.isDirectory()) {
      String fileName = String(file.name());
      if (fileName.startsWith("foto_") && fileName.endsWith(".jpg")) {
        // Extraer la parte numérica del nombre (ej: "foto_00012.jpg" -> "00012")
        String numStr = fileName.substring(5, fileName.indexOf('.'));
        unsigned long num = numStr.toInt();
        if (num > maxNum) {
          maxNum = num;
        }
      }
    }
    file = root.openNextFile();
  }
  return maxNum;
}

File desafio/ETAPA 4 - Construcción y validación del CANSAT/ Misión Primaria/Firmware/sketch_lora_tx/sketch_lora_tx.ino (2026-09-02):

/*  Transmisor TX - E.E.S.T. N.°5 "Amancio Williams"
    CONAE Cansat Secundario Edición 2026    
    
    Transmisor TX Oficial para Heltec WiFi LoRa 32 V3 
    Usa RadioLib para el chip SX1262 
*/

#include <RadioLib.h>
#include <Adafruit_BMP280.h>
#include <Adafruit_MPU6050.h>
#include <Adafruit_Sensor.h>
#include <Wire.h>

char Version[] = "v3.0 BMP280 - Heltec V3";

#define HELTEC_NSS 8
#define HELTEC_DIO1 14
#define HELTEC_RST 12
#define HELTEC_BUSY 13
#define LED 35
#define VEXT_PIN 36

#define I2C_SDA 41
#define I2C_SCL 42

SX1262 radio = new Module(HELTEC_NSS, HELTEC_DIO1, HELTEC_RST, HELTEC_BUSY);
Adafruit_BMP280 bmp;   // Objeto BMP280
Adafruit_MPU6050 mpu;  // Objeto MPU6050

#define SERIAL_BAUDRATE 115200
#define INTERVAL_TIME_TX 1000

#define LORA_FREQUENCY 915.0
#define LORA_BANDWIDTH 125.0
#define LORA_SPREAD_FACTOR 7
#define LORA_CODING_RATE 5
#define LORA_SYNC_WORD 0xF3
#define LORA_POWER 17

double baseline;
double T, P, A;
unsigned int pktNumber = 0;
sensors_event_t mpu_a, mpu_g, mpu_temp;

void setup() {
  pinMode(VEXT_PIN, OUTPUT);
  digitalWrite(VEXT_PIN, LOW);  // Alimenta I2C / Pantalla
  delay(100);

  pinMode(LED, OUTPUT);
  digitalWrite(LED, HIGH);

  Serial.begin(SERIAL_BAUDRATE);
  delay(1000);

  // Inicializar LoRa
  Serial.println("\n--- Inicializando Transmisor (BMP280) ---");
  int state = radio.begin(LORA_FREQUENCY,
                          LORA_BANDWIDTH,
                          LORA_SPREAD_FACTOR,
                          LORA_CODING_RATE, LORA_SYNC_WORD, LORA_POWER);

  if (state == RADIOLIB_ERR_NONE) {
    Serial.println("¡LoRa RadioLib OK!");
  } else {
    Serial.print("Error LoRa, código: ");
    Serial.println(state);
    while (true)
      ;
  }

  // Inicializar I2C
  Wire.begin(I2C_SDA, I2C_SCL);
  bool bmpIsInit = false;

  do {
    delay(1000);
    // Probamos primero con dirección 0x76 (típica del BMP280) y luego 0x77
    if (bmp.begin(0x76) || bmp.begin(0x77)) {
      Serial.println("¡BMP280 encontrado e iniciado OK!");
      readTempPressure();
      baseline = P;
      Serial.print("Presion Base: ");
      Serial.print(baseline * 0.01);
      Serial.println(" hpa");
      bmpIsInit = true;
      digitalWrite(LED, LOW);
    } else {
      Serial.println("Buscando BMP280 en GPIO 41/42...");
    }
  } while (!bmpIsInit);

  // Inicializar MPU6050
  mpuInit();
}

void loop() {
  readTempPressure();
  mpuRead();
  mpuPrint();

  pktNumber++;
  if (pktNumber >= 65500) pktNumber = 0;

  // Packet Number (1), Presion Base (2), Presion Absoluta (3), Altura (4)
  // Temperatura (5), Aceleracion X (6), Aceleracion Y (7),
  // Aceleracion  Z (8), Velocidad Angular X (9), Velocidad Angular Y (10)
  // Velocidad Angular Z (11)
  String packetData = String(pktNumber) + "," + String(baseline * 0.01, 2) + "," + String(P * 0.01, 2) + "," + String(A, 2)
                      + "," + String(T, 1) + "," + String(mpu_a.acceleration.x) + "," + String(mpu_a.acceleration.y)
                      + "," + String(mpu_a.acceleration.z) + "," + String(mpu_g.gyro.x) + "," + String(mpu_g.gyro.y)
                      + "," + String(mpu_g.gyro.z);

  Serial.print("TX - Version ");
  Serial.println(Version);
  Serial.print("Packet Number: ");
  Serial.println(pktNumber);
  Serial.print("Enviando: ");
  Serial.println(packetData);

  digitalWrite(LED, HIGH);

  int state = radio.transmit(packetData);

  if (state == RADIOLIB_ERR_NONE) {
    Serial.println("Paquete enviado con éxito.");
  } else {
    Serial.print("Error al transmitir: ");
    Serial.println(state);
  }
  digitalWrite(LED, LOW);
  Serial.println("=====================================================================");
  delay(INTERVAL_TIME_TX);
}

void readTempPressure() {
  T = bmp.readTemperature();
  P = bmp.readPressure();
  A = bmp.readAltitude(1013.25);  // Presión promedio a nivel del mar
}

void mpuInit() {
  Serial.println("Adafruit MPU6050 Init!");

  // Try to initialize!
  if (!mpu.begin()) {
    Serial.println("No se encuentra el chip MPU6050");
    while (1) {
      delay(10);
    }
  }
  Serial.println("MPU6050 encontrado!");

  mpu.setAccelerometerRange(MPU6050_RANGE_8_G);
  Serial.print("Rango del Acelerometro: ");
  switch (mpu.getAccelerometerRange()) {
    case MPU6050_RANGE_2_G:
      Serial.println("+-2G");
      break;
    case MPU6050_RANGE_4_G:
      Serial.println("+-4G");
      break;
    case MPU6050_RANGE_8_G:
      Serial.println("+-8G");
      break;
    case MPU6050_RANGE_16_G:
      Serial.println("+-16G");
      break;
  }
  mpu.setGyroRange(MPU6050_RANGE_500_DEG);
  Serial.print("Rango del Giroscopio: ");
  switch (mpu.getGyroRange()) {
    case MPU6050_RANGE_250_DEG:
      Serial.println("+- 250 deg/s");
      break;
    case MPU6050_RANGE_500_DEG:
      Serial.println("+- 500 deg/s");
      break;
    case MPU6050_RANGE_1000_DEG:
      Serial.println("+- 1000 deg/s");
      break;
    case MPU6050_RANGE_2000_DEG:
      Serial.println("+- 2000 deg/s");
      break;
  }

  mpu.setFilterBandwidth(MPU6050_BAND_21_HZ);
  Serial.print("Ancho de banda del Filtro: ");
  switch (mpu.getFilterBandwidth()) {
    case MPU6050_BAND_260_HZ:
      Serial.println("260 Hz");
      break;
    case MPU6050_BAND_184_HZ:
      Serial.println("184 Hz");
      break;
    case MPU6050_BAND_94_HZ:
      Serial.println("94 Hz");
      break;
    case MPU6050_BAND_44_HZ:
      Serial.println("44 Hz");
      break;
    case MPU6050_BAND_21_HZ:
      Serial.println("21 Hz");
      break;
    case MPU6050_BAND_10_HZ:
      Serial.println("10 Hz");
      break;
    case MPU6050_BAND_5_HZ:
      Serial.println("5 Hz");
      break;
  }
  Serial.println("");
}

void mpuRead() {
  mpu.getEvent(&mpu_a, &mpu_g, &mpu_temp);
}

void mpuPrint() {
  Serial.print("Acceleration X: ");
  Serial.print(mpu_a.acceleration.x);
  Serial.print(", Y: ");
  Serial.print(mpu_a.acceleration.y);
  Serial.print(", Z: ");
  Serial.print(mpu_a.acceleration.z);
  Serial.println(" m/s^2");

  Serial.print("Rotation X: ");
  Serial.print(mpu_g.gyro.x);
  Serial.print(", Y: ");
  Serial.print(mpu_g.gyro.y);
  Serial.print(", Z: ");
  Serial.print(mpu_g.gyro.z);
  Serial.println(" rad/s");

  Serial.print("Temperature: ");
  Serial.print(mpu_temp.temperature);
  Serial.println(" degC");

  Serial.println("");
}

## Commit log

2026-08-21 add Material para docentes
2026-08-21 add etapa 1: capacitación
2026-08-21 add foto llegada del kit a la escuela
2026-08-21 add etapa 4: construcción y validación
    [Gabinete.FCStd]
2026-08-21 add Kicad PCB Project
    [cansat_pcb.kicad_pcb, cansat_pcb.kicad_sch]
2026-08-28 add Heltec Step file
    [Heltec_ESP32_WIFI.Step, Heltec_V3.step]
2026-08-28 Update FC Project
    [Estacion_Terrena.FCStd, Gabinete.FCStd]
2026-08-31 add case
    [Heltec_ESP32_WIFI.Step, Heltec_V3.step, Meshtastic_heltec_v3_gehäuse_1.1.STL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]
2026-08-31 update dir
    [Heltec_ESP32_WIFI.Step, Heltec_V3.step]
2026-09-01 add 3D print files
    [Meshtastic_heltec_v3_gehäuse_1.1.3mf]
2026-09-01 add LoRa Board Image
2026-09-02 update dirs (case)
    [Heltec_ESP32_WIFI.Step, Heltec_V3.step, Meshtastic_heltec_v3_gehäuse_1.1.3mf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]
2026-09-02 add capturas de pantalla Dashboard
2026-09-02 update schematic: MPU6050
    [cansat_pcb.kicad_sch]
2026-09-02 update schematic
    [cansat_pcb.kicad_sch]
2026-09-15 update pcb
    [cansat_pcb.kicad_sch]
2026-09-15 add 3d files
    [cansat_antir_1.0.blend, cansat_antir_1.0_BODY.stl, cansat_antir_1.0_LID.stl]
2026-10-02 add ESP32-Cam files
2026-10-05 update case
    [cansat_antir_1.0_BODY.stl, cansat_antir_1.0_LID.stl]
2026-10-05 add project & gcode
    [cansat_antir_1.0.3mf]
2026-10-20 update stl parts
2026-11-06 update cansat sch & pcb
2026-11-06 add ESP32-CAM PCB & SCH
